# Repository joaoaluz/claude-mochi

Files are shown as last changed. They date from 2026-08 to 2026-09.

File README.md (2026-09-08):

# claude-mochi

Um mochi de mesa cujos **olhos indicam o consumo de tokens do Claude Code**.

Quanto mais da sua cota de **5 horas** você gasta, mais os olhos se fecham e
mais quente fica a cor da íris — verde → âmbar → vermelho. A barrinha embaixo
mostra o mesmo número, com precisão que a pálpebra só sugere. Passou de 95%
(ou rodou `/compact`), o mochi fica de olhos tontos (`X_X`). Sem notícias do
PC por 30 s, ele cochila.

Olhos e barra escolhem a métrica de forma independente, em `OLHOS_METRICA` e
`BARRA_METRICA` no `.ino`: qualquer um dos dois pode apontar para a janela de
contexto em vez do limite de 5 horas.

Inspirado no [clawd-mochi](https://github.com/yousifamanuel/clawd-mochi) do
Yousif Amanuel — mesma ideia de hardware, mas ligado ao Claude Code em vez de
funcionar offline por um hotspot.

> Projeto independente de fã, sem vínculo com a Anthropic.

---

**Vai construir?** Siga **[docs/PASSO-A-PASSO.md](docs/PASSO-A-PASSO.md)** — o
caminho completo em 8 fases, do saquinho de peças ao case impresso, com um teste
que fecha cada fase.

**Só a bancada?** **[docs/PROTOBOARD.md](docs/PROTOBOARD.md)** cobre a montagem na
protoboard em mais detalhe, sem case e sem solda no circuito. O firmware roda uma
animação de boot que valida display e fiação sem depender do PC.

**O que aparece na tela:** [`docs/tela/tela-mochi.svg`](docs/tela/tela-mochi.svg) —
todas as telas em escala 1:1 (rampa de contexto, piscar, cochilar, `X_X`) mais uma
proposta de expressões vindas dos hooks. O desenho é gerado por
`docs/tela/gera_svg.py`, que copia as constantes e a matemática inteira do
`.ino`; mexeu no firmware, rode o script de novo.

---

## Como funciona

A **status line** do Claude Code roda a cada mensagem do assistente e recebe um
JSON no stdin que já traz tudo pronto:

```json
"context_window": { "used_percentage": 72, "context_window_size": 200000 },
"rate_limits":    { "five_hour": { "used_percentage": 41 } },
"cost":           { "total_cost_usd": 1.2345 }
```

**Por que não usar a API ou um scraper da página de usage:** a Usage & Cost
Admin API exige uma *Admin API key* (`sk-ant-admin01-…`), que só existe para
organizações do Console — a documentação diz explicitamente que *"the Admin API
is unavailable for individual accounts"*. Além disso ela mede o consumo da API
de desenvolvedor, não o da assinatura Pro/Max, e os dados chegam com ~5 min de
atraso em buckets de 1m/1h/1d. A status line é instantânea, local, sem chave e
funciona em qualquer tipo de conta.

---

## Escolha a ligação: serial ou Wi-Fi

O firmware suporta as duas. Escolha no topo do `.ino` (`LINK_SERIAL` /
`LINK_WIFI`) e na variável `MOCHI_LINK` do lado do PC.

### Serial pelo USB — **padrão e recomendado**

```
Claude Code ──stdin──▶ statusline ──escreve arquivo──▶ ponte (mochi.py) ──USB──▶ ESP8266
                       (nunca toca                     (abre a porta UMA vez,
                        na porta serial)                reenvia a cada 5 s)
```

Funciona **em qualquer rede, ou sem rede nenhuma**. É o modo certo se:

- o PC está numa rede e o mochi em outra (o caso comum: Wi-Fi corporativo com
  WPA2-Enterprise, portal cativo ou registro de MAC, onde o ESP8266 não entra);
- a rede tem **isolamento de cliente** (*AP isolation*), que bloqueia tráfego
  entre dispositivos — a maioria das redes de empresa tem, e nesse caso o modo
  Wi-Fi não funcionaria **nem estando na mesma SSID**;
- o mDNS não atravessa a segmentação de VLAN da rede.

De brinde: sem credenciais no firmware, e como o rádio é desligado sobra RAM
para o display e o consumo cai ~20 mA. O mochi já vai estar no USB para ter
energia de qualquer forma.

**O detalhe que define a arquitetura:** no ESP8266 (NodeMCU / D1 mini), abrir a
porta serial aciona DTR/RTS e **reinicia a placa**. Se a status line abrisse a
porta a cada mensagem, o mochi reiniciaria dezenas de vezes por sessão. Por isso
existe o daemon: ele abre a porta uma única vez, e a status line só escreve um
arquivo de estado (escrita atômica: grava em `.tmp` e renomeia).

Um FIFO seria o instinto natural aqui, mas **escrever num FIFO sem leitor trava
para sempre** — penduraria o seu terminal se o daemon morresse. Arquivo comum
degrada em silêncio: fica velho e pronto.

O daemon reenvia o estado a cada 5 s mesmo sem mudança, então se o ESP reiniciar
ele se recupera sozinho.

### Wi-Fi (HTTP na rede local)

Só use se o PC e o mochi estiverem na **mesma rede sem isolamento de cliente** —
tipicamente a sua rede de casa. O ESP entra como cliente (não cria hotspot) e
responde em `http://mochi.local`.

| Rota | Efeito |
|---|---|
| `GET /` | página de status |
| `GET /state` | JSON com o estado atual |
| `GET /tokens?ctx=42&win=63&state=busy` | atualiza os olhos |
| `GET /backlight?on=0\|1` | apaga/acende a tela |

### E se o mochi ficar em casa e você no trabalho?

Aí não tem jeito de ser direto: seria preciso um intermediário na internet
(um broker MQTT público como o HiveMQ, ou um endpoint que o ESP fica
consultando). Dá para fazer, mas vale perguntar se compensa — se o mochi está
em casa, você não está olhando para ele. O caso que faz sentido é ele estar na
sua mesa, ao lado do notebook, e aí **serial resolve.**

---

## Lista de materiais

| Item | Obs |
|---|---|
| **ESP8266** (NodeMCU, Wemos D1 mini ou ESP-12) | 3,3 V — ideal para o display |
| **Display ST7789 240×240 SPI**, 1.54" ou 1.3" | veja a seção abaixo. **VCC só em 3,3 V, nunca 5 V** |
| Jumpers dupont fêmea-fêmea 10 cm | 7 fios (ou 6, se o módulo não tiver CS) |
| 2× parafuso M2×6 mm | prende o display |
| Fita dupla face fina | fixa a placa do ESP |
| Cabo USB | alimentação **e** dados (no modo serial os dois são usados) |
| Filamento PLA ou PETG | branco leitoso fica ótimo |

**Opcionais que valem a pena:** insertos roscados M2 (heat-set), botão tátil
6×6 mm para trocar de modo, buzzer piezo passivo (bipe no hook `Stop`), 1–3
LEDs WS2812B para as bochechas.

**Não é preciso nenhum resistor.** O ESP8266 e o display são ambos 3,3 V — não
há divisor de tensão, level shifter nem pull-up neste circuito.

### Qual display comprar

**Primeira escolha: ST7789 IPS 1.54" 240×240 SPI.** Área ativa de ~27,7 mm
contra ~23,4 mm da versão 1.3" — num rosto de mochi esses milímetros viram
olhos visivelmente maiores. É também o tamanho usado pelo projeto de referência.

**Alternativa igualmente boa: 1.3" 240×240 ST7789**, mais barata e bem mais
comum no Brasil. Mesmo controlador, mesma resolução, **firmware idêntico** — só
muda `scr_active` no `.scad`.

**7 ou 8 pinos, tanto faz.** Os módulos vêm em duas variantes:

| Variante | Pinos | CS |
|---|---|---|
| 8 pinos | GND VCC SCL SDA RES DC BLK **CS** | tem |
| 7 pinos | GND VCC SCL SDA RES DC BLK | não tem — fica em GND internamente |

A única desvantagem do sem-CS é não poder dividir o barramento SPI com outro
periférico, e aqui o display é o único dispositivo no SPI. Se o seu não tiver
CS, troque `#define TFT_CS D8` por `#define TFT_CS -1` no topo do `.ino` e não
ligue esse fio — sobra um GPIO.

**Checklist para aprovar um anúncio:**

| | |
|---|---|
| ✅ **Aprova** | controlador **ST7789** (ou ST7789V / ST7789VW), **240×240**, **1.54"** ou **1.3"**, **SPI**, **3,3 V** |
| ❌ **Rejeita** | ST7735 / ILI9341 / ILI9488 (outro controlador, outro código) · 240×280, 135×240, 320×240 (resolução diferente, quebra o layout dos olhos) · **GC9A01** (funciona, mas é redondo — é o caminho dos dois olhos separados, outro projeto) · só 5 V · com touch (não usamos e encarece) |
| ⚠️ **Confirmar** | quantos pinos (7 sem CS / 8 com CS) · barra de pinos soldada ou solta |

> **Duas armadilhas que não aparecem na lista de peças:**
>
> 1. O módulo quase sempre vem com a **barra de pinos solta, não soldada** — sem
>    soldar não encaixa em jumper nem protoboard. Precisa de ferro de solda.
> 2. O **cabo USB precisa ter fios de dados**. Muito cabo barato é só de carga e
>    nem enumera a porta serial — no modo serial isso é fatal, e o sintoma é
>    confuso (a placa liga e a tela acende, mas nenhuma porta aparece no PC).

**O Arduino Uno não entra neste projeto.** Sem Wi-Fi, lógica 5 V (mataria o
display de 3,3 V sem level shifter) e 2 KB de RAM — não anima 240×240. E se a
ideia fosse o próprio microcontrolador chamar a API da Anthropic, precisaria de
TLS: o Uno não tem, e o ESP8266 gastaria 16–30 KB de RAM dos 80 KB só no
handshake, brigando com o display — além de exigir a chave gravada no firmware.

---

## Ligações

Alimente o display **apenas com 3,3 V**.

| Display | ESP8266 | GPIO |
|---|---|---|
| VCC | 3V3 | — |
| GND | GND | — |
| SCL / SCK | D5 | GPIO14 |
| SDA / MOSI | D7 | GPIO13 |
| RES / RST | D2 | GPIO4 |
| DC | D1 | GPIO5 |
| CS | D8 | GPIO15 — *só se o módulo tiver esse pino* |
| BLK | **3V3** | ou D6/GPIO12, se quiser controlar o brilho (`USE_BLK_PIN 1`) |

`SCK` e `MOSI` são fixos (SPI por hardware); os outros são configuráveis no topo
do `.ino`. Evite D0/D3/D4 para o display — são pinos de boot no ESP8266.

Módulo de 7 pinos (sem CS): pule essa linha e use `#define TFT_CS -1`.

---

## Firmware

1. Arduino IDE 2.x → **Preferences → Additional Boards Manager URLs**:
   `https://arduino.esp8266.com/stable/package_esp8266com_index.json`
2. **Boards Manager** → instalar *esp8266 by ESP8266 Community*.
3. **Library Manager** → instalar *Adafruit GFX Library* e *Adafruit ST7735 and
   ST7789 Library*.
4. Abrir `firmware/claude_mochi/claude_mochi.ino`, conferir `LINK_SERIAL` /
   `LINK_WIFI` no topo, selecionar a placa e gravar.
5. **Só no modo Wi-Fi:** antes de gravar,
   `cp firmware/claude_mochi/config.example.h firmware/claude_mochi/config.h`
   e preencha SSID e senha (`config.h` está no `.gitignore`).

**Se a imagem sair com ruído:** baixe `setSPISpeed` de `40000000` para
`20000000`. **Se sair de cabeça para baixo ou espelhada:** ajuste
`tft.setRotation(0..3)`.

### Protocolo serial

Uma linha por atualização, pares `chave=valor` separados por espaço, terminada
em `\n`, a 115200 bps. Chaves: `ctx`, `win`, `state`. O firmware responde `ok`.

```
ctx=42 win=63 state=busy
```

Dá para testar à mão pelo Monitor Serial da Arduino IDE antes de montar o resto.

---

## Lado do PC

Dois caminhos para o mesmo resultado:

| | Quando usar | Precisa de |
|---|---|---|
| **`host/mochi.py`** | Windows, macOS, Linux. **Único que funciona no Windows.** | Python + `pyserial` |
| `host/*.sh` | Só se você já tem os scripts bash rodando no Linux/macOS | `bash`, `jq`, `curl` |

O `mochi.py` faz sozinho o que antes eram três arquivos: status line, hooks e
ponte serial. Ele não usa `bash` nem `jq` de propósito — no Windows nenhum dos
dois existe por padrão, e a status line do Claude Code lá é executada pelo Git
Bash (quando instalado) ou pelo PowerShell.

### Windows + Claude Desktop — plugou, funcionou

```bash
pip install pyserial
python host/mochi.py install
```

E reinicie o Claude Desktop. Só isso.

O `install`:

- copia o `mochi.py` para `~/.claude/`;
- faz backup do seu `settings.json` (`settings.json.bak-mochi`);
- escreve a `statusLine` e os hooks, **preservando** o que já estava lá;
- sobe a ponte serial.

Rodar de novo é seguro — ele troca a própria configuração em vez de duplicar.

A partir daí não há passo manual nenhum: **a status line sobe a ponte sozinha**
quando percebe que não tem nenhuma viva. Abrir o notebook, plugar o mochi e
abrir o Claude já basta. Sem systemd, sem Agendador de Tarefas.

Para conferir tudo de uma vez:

```bash
python host/mochi.py doctor
```

Ele mostra as portas com uma nota cada, qual foi escolhida, se a ponte está
viva, o que a status line publicou por último e se o `settings.json` está
apontando para o mochi.

### Achando a placa

`mochi.py ports` dá uma nota para cada porta em vez de chutar:

```
 nota  porta    descricao                              motivo
  100  COM5     USB-SERIAL CH340 (COM5)                adaptador conhecido: CH340
 -100  COM3     Standard Serial over Bluetooth link    ignorada (bluetooth)
```

Isso importa mais do que parece: num Windows típico a maioria das portas COM é
Bluetooth — a máquina onde isto foi testado tinha oito. A escolha combina
VID:PID conhecido (CH340, CH9102, CP2102, FT232, ESP32 nativo…), descrição, e
uma lista de exclusão para portas virtuais.

Quando sobra mais de uma candidata forte, a ponte **pergunta para cada uma**:
manda uma linha e vê quem responde `ok`. Duas placas ligadas juntas deixaram de
ser um impasse.

A ponte também redescobre a porta a cada reconexão e guarda a última que
funcionou em `~/.claude/mochi-port`. Trocar o cabo de entrada USB (COM5 → COM7)
se resolve sozinho, sem reiniciar nada.

Para forçar: `--port COM7` ou a variável `MOCHI_PORT`.

### Comandos

```bash
python host/mochi.py doctor            # diagnóstico completo
python host/mochi.py ports             # portas e a nota de cada uma
python host/mochi.py start | stop | restart
python host/mochi.py bridge -v         # ponte em primeiro plano, com log
python host/mochi.py send "ctx=50 win=80 state=busy"   # teste direto
python host/mochi.py uninstall         # tira do settings.json
```

Log da ponte de fundo: `~/.claude/mochi-bridge.log`.

### Uma ponte de cada vez

Só um processo pode segurar a porta serial. Se aparecer *"a porta está ocupada"*,
o culpado é quase sempre:

1. **outra ponte já rodando — inclusive dentro do WSL.** Uma ponte no WSL e outra
   no Windows disputando a mesma COM é o erro mais comum de quem migrou. Use
   `mochi.py stop`, ou encerre a do WSL.
2. o Monitor Serial da Arduino IDE aberto.

A ponte se recusa a subir se já houver outra viva, e a mensagem de erro diz
exatamente isso em vez de mostrar um `PermissionError` cru.

### Linux e macOS

O `mochi.py` funciona igual (`python3 host/mochi.py install`). Se preferir os
scripts bash antigos, eles continuam válidos:

```bash
cp host/statusline-mochi.sh host/mochi-mode.sh ~/.claude/
chmod +x ~/.claude/statusline-mochi.sh ~/.claude/mochi-mode.sh
```

e copie o bloco `statusLine`/`hooks` de `host/settings.example.json`.

No Linux, se der erro de permissão na porta: `sudo usermod -aG dialout $USER` e
reconecte a sessão.

Para deixar a ponte rodando como serviço em vez de contar com o autostart —
systemd de usuário:

```ini
# ~/.config/systemd/user/mochi.service
[Unit]
Description=claude-mochi serial bridge
[Service]
ExecStart=%h/.claude/mochi.py bridge
Restart=always
RestartSec=3
[Install]
WantedBy=default.target
```

```bash
systemctl --user daemon-reload && systemctl --user enable --now mochi
```

No macOS o equivalente é um `launchd` plist em `~/Library/LaunchAgents/`.

### Variáveis de ambiente

| Variável | Padrão | Para quê |
|---|---|---|
| `MOCHI_PORT` | autodetect | força a porta serial |
| `MOCHI_LINK` | `serial` | `serial`, `http` ou `both` |
| `MOCHI_HOST` | `mochi.local` | destino no modo http |
| `MOCHI_AUTOSTART` | `1` | `0` desliga o autostart da ponte |
| `MOCHI_STATE_FILE` / `MOCHI_MODE_FILE` | `~/.claude/mochi-*` | onde ficam os arquivos de estado |

### Modo Wi-Fi

```bash
export MOCHI_LINK=http
export MOCHI_HOST=mochi.local     # ou o IP, se o mDNS não funcionar na sua rede
```

Nesse modo não precisa da ponte: a status line fala direto com o ESP.

### Skill: instalar em outra máquina

O repositório traz uma skill em `.claude/skills/claude-mochi/`. Com o
repositório clonado, plugue o mochi e peça ao Claude *"instala o mochi aqui"* —
ela cobre instalação, diagnóstico e os erros comuns (porta ocupada, driver
CH340 faltando, cabo só de carga, status line que não aparece no Windows).

---

## Case 3D

Há **dois** modelos no repositório, ainda não consolidados:

| pasta | para qual placa | estado |
|---|---|---|
| `case/mochi.scad` | ESP8266 + display, **com** janela de tela | renderizado e fechado; medidas de componente ainda por conferir |
| `hardware/mochi.scad` | Raspberry Pi Zero / Pico, **sem** janela de tela | renderizado, sólido fechado, STLs em [`hardware/stl/`](hardware/stl) |
| `case/clawd_tela.scad` | **forma do Clawd**, só o display dentro | corta a janela nas malhas do `clawd_mochi.3mf`; as duas peças fecham (`Volumes: 2`) |

O `hardware/` nasceu de um pedido separado, feito sem saber que o `case/` já
existia — então é o modelo validado geometricamente, mas mira a placa errada
para este projeto. O caminho natural é levar para o `case/` o que foi provado
ali (perfil do corpo, pilares de canto embutidos na parede, `assert` de encaixe
da placa) e ficar com um modelo só. Até lá, **o case do projeto é o `case/`** — o
`hardware/` fica como referência, com guia próprio em
[`hardware/README.md`](hardware/README.md) e `make stl` na raiz.

### case/ — ESP8266 com display

`case/mochi.scad` é um modelo **paramétrico** em OpenSCAD. O corpo é o casco
convexo de 12 esferas em três andares (base larga, barriga, cúpula), o que dá a
forma redonda de mochi e permite calcular a parede interna exata só reduzindo o
raio das esferas — sem `minkowski()`, que é lentíssimo.

```bash
openscad -D 'part="front"' -o front.stl case/mochi.scad
openscad -D 'part="back"'  -o back.stl  case/mochi.scad
```

Use `part="preview"` para ver as duas metades montadas.

> ⚠️ **A geometria já foi renderizada; as medidas de componente não.**
> As duas metades exportam como um sólido fechado e conexo cada uma (CGAL:
> `Simple: yes`, uma peça por STL). O que continua sendo estimativa são as
> medidas do seu display e da sua placa: antes de imprimir, **meça com
> paquímetro** e preencha as variáveis no topo do arquivo — principalmente
> `scr_pcb_w/h`, `scr_active`, `scr_active_dy`, `brd_l/w` e `usb_w/h/z`.
> Os valores atuais são estimativas para um ST7789 1.54" e um Wemos D1 mini
> (NodeMCU v3 é bem maior: 58 × 31 mm). E ninguém imprimiu isto ainda.

**Impressão:** PLA ou PETG, camada 0,15–0,20 mm, 15% de preenchimento. Imprima a
casca frontal com o rosto virado para a mesa — a janela sai sem suporte (a
orientação `part="front"` já faz isso). Folga de 0,3 mm em volta do display e
0,3 mm no lábio da tampa.

### case/clawd_tela.scad — a forma do Clawd, com janela

Trabalha em cima das **malhas do seu `clawd_mochi.3mf`** (Bambu Studio),
extraídas para `models/upstream/3mf-corpo.stl` e `3mf-chapa.stl`. São as duas
peças do [clawd-mochi](https://github.com/yousifamanuel/clawd-mochi): chapa
frontal de 2 mm e corpo com cavidade **passante** de 48,50 × 32,25 mm — no seu
projeto o corpo está achatado em Z, de 38 para **28 mm** (`m22 = 0,7368` na
matriz do objeto). Esse achatamento está reproduzido em `escala_z`.

O modelo original tem a cara vazada (boca de 9 × 3,25 mm e dois furinhos de
3,5 mm nas orelhas), não uma tela. O `.scad` acrescenta:

1. **janela** da área ativa, 28,5 × 28,5 mm, com chanfro de 45° na face de fora
2. **tampa da boca**, que ficaria mordida pela borda da janela
3. **moldura interna** que segura a PCB contra a chapa, com saia a 45° para
   imprimir sem suporte nessa região

As malhas de origem **não são versionadas** (`.gitignore` barra `*.stl` e
`*.3mf`, e são geometria de terceiro sob CC BY-NC-SA). Regenere a partir do seu
projeto do fatiador e exporte as peças:

```bash
python3 models/extrai_3mf.py clawd_mochi.3mf
```

```bash
make clawd
```

Ou peça por peça, sem `make`:

```bash
openscad -o case/stl/clawd-chapa.stl -D 'part="chapa"' case/clawd_tela.scad
```

Sem parafuso nenhum: a chapa **cola** no aro do corpo. Só o display vai dentro;
o ESP8266 fica fora e os fios saem pelo fundo, que já é aberto.

A placa do display (31,5 mm) contra a cavidade (32,25 mm) deixa **0,375 mm por
lado**. Aperta. Existe `alargar` para comer parte da parede de trás, mas ele só
corta os `alargar_z` mm de cima: a faixa maciça em Y −10,75..−12,5 fecha o fundo
da cavidade e é de onde saem as quatro perninhas — cortá-la inteira solta as
perninhas do corpo.

> ⚠️ As medidas do display são **estimativa** (`pcb_x`, `pcb_y`, `ativa`,
> `ativa_dx`). Meça o seu módulo com paquímetro antes de imprimir.

**Voltando para o fatiador:** `make clawd-3mf` gera `clawd_mochi_tela.3mf`, o seu
projeto com as duas malhas trocadas — todos os ajustes de fatiamento, perfis e a disposição no prato
foram preservados; só a escala em Z saiu da matriz e foi assada na malha. As
miniaturas guardadas ainda mostram o modelo antigo, sem janela; elas se
regeneram quando você fatiar.

**Licença:** os modelos de origem são CC BY-NC-SA 4.0 — não comercial, com
atribuição. O que sai daqui é derivado e herda a mesma licença.

### Alternativa

Os modelos do projeto original (`models/clawd_mochi/clawd_mochi_v1.stl` e
`.3mf`) estão sob **CC BY-NC-SA 4.0** — uso não comercial, com atribuição e
compartilhamento pela mesma licença. Só que foram desenhados em volta de um
ESP32-C3 Super Mini (22,5 × 18 mm); um NodeMCU não cabe. Se o seu ESP8266 for um
Wemos D1 mini, vale testar; se for NodeMCU, o `.scad` daqui é o caminho.

---

## Próximos passos possíveis

- Dois displays redondos GC9A01 1.28" — um olho físico por tela, com contexto num
  e limite de 5h no outro (compartilham SPI, cada um com seu CS).
- Buzzer no hook `Stop` para avisar que a tarefa terminou.
- LEDs de bochecha acompanhando a cor da íris.
- Bateria LiPo + TP4056 com proteção (o backlight puxa 30–60 mA, então a
  autonomia real é de poucas horas).

## Licença

Código sob MIT. Se você reaproveitar os STLs do `clawd-mochi`, eles seguem sob
CC BY-NC-SA 4.0 do autor original.

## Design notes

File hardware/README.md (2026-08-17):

# Modelo para impressão 3D — carcaça do claude-mochi

Carcaça paramétrica do assistente de mesa, feita em OpenSCAD. São **duas peças**,
as duas impressas **sem suporte nenhum**:

| peça | arquivo | o que tem |
|---|---|---|
| `casca` | `stl/<placa>-casca.stl`  | corpo do mochi, oco, rostinho gravado, grelha frontal, aberturas das portas e os 4 pilares de parafuso |
| `base`  | `stl/<placa>-base.stl` | tampa do fundo, espaçadores da PCB, rasgos de ventilação, escareados e rebaixos para pés de borracha |

<p align="center">
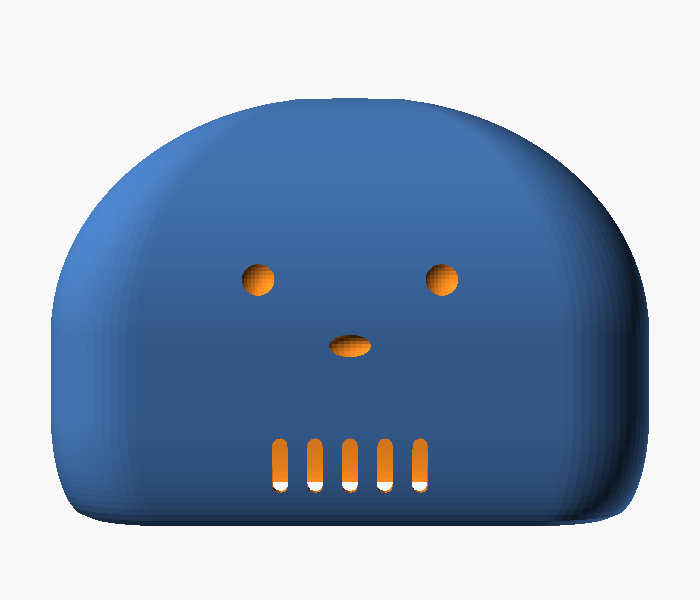
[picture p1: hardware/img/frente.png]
Vista frontal da casca
  
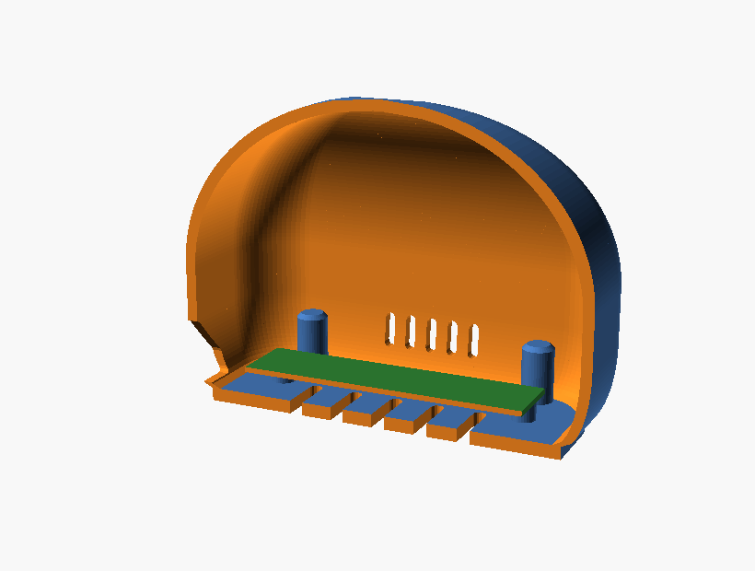
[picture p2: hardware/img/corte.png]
Corte mostrando o interior
  
</p>
<p align="center">
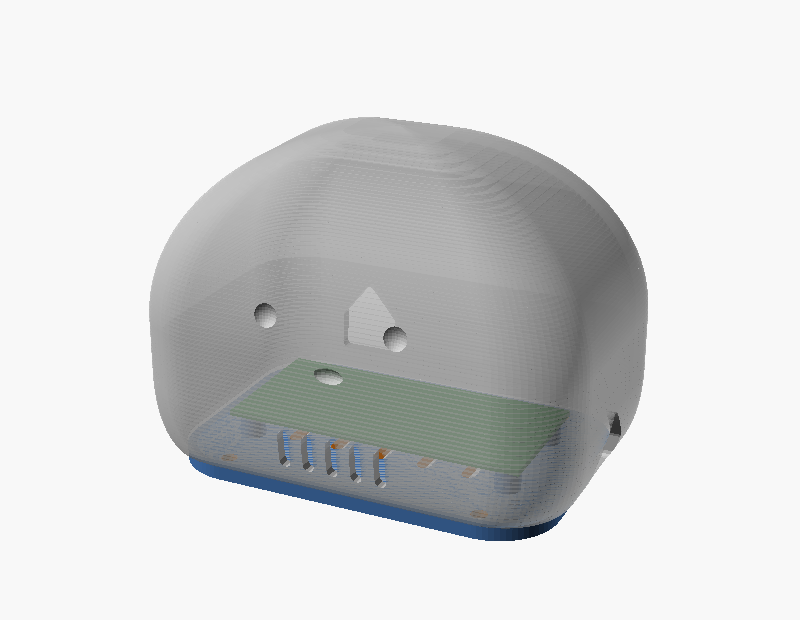
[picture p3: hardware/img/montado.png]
Conjunto montado
  
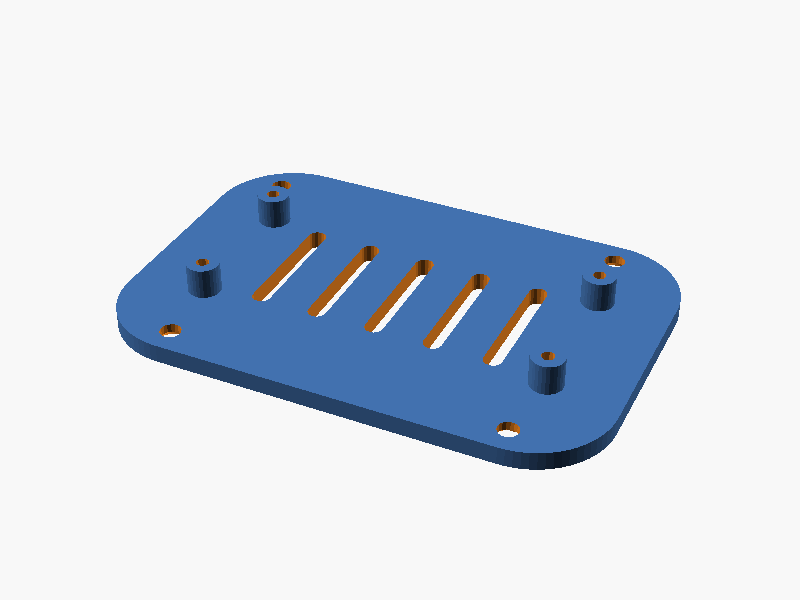
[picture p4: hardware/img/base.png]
Base com os espaçadores
  
</p>

## Medidas

| placa | corpo (L × P × A) | altura total com a base | material (par completo) |
|---|---|---|---|
| `pi_zero` (Pi Zero / Zero 2 W) | 94 × 64 × 68 mm | 71 mm | ≈ 60 g de PLA |
| `pico` (Raspberry Pi Pico) | 76 × 52 × 56 mm | 59 mm | ≈ 40 g de PLA |

Cabe em qualquer mesa de impressão a partir de 100 × 100 mm.

## Lista de material

- 4 × parafuso **M3 × 12** auto‑atarraxante, cabeça escareada — prende a base na casca
- 4 × parafuso **M2,5 × 6** (Pi Zero) ou **M2 × 6** (Pico) — prende a PCB nos espaçadores
- 4 × pé adesivo de borracha Ø 9 mm (opcional, há rebaixo para eles)

Prefere insertos térmicos M3 nos pilares? Gere a casca com
`-D screw_pilot=4.0` e instale os insertos com o ferro de solda.

## Gerando os arquivos

Os STL já estão em [`stl/`](stl), prontos para fatiar. Para regerar:

```bash
sudo apt install openscad     # ou: brew install --cask openscad
make stl                      # exporta as 4 peças em hardware/stl/
```

Peça por peça, direto no OpenSCAD:

```bash
openscad -o casca.stl -D 'part="casca"' -D 'board_name="pi_zero"' hardware/mochi.scad
openscad -o base.stl  -D 'part="base"'  -D 'board_name="pi_zero"' hardware/mochi.scad
```

Para olhar antes de imprimir, abra `hardware/mochi.scad` no OpenSCAD e use o
Customizer (todos os parâmetros estão agrupados). O parâmetro `part` aceita:

- `"casca"` / `"base"` — cada peça sozinha
- `"chapa"` — as duas lado a lado, já na orientação de impressão
- `"montado"` — conjunto montado, com a placa desenhada por dentro
- `"corte"` — meia‑seção, para conferir folgas e altura das aberturas

## Perfil de fatiamento

| item | valor |
|---|---|
| orientação | **exatamente como está no STL** — casca com a boca para baixo, base com os espaçadores para cima |
| suportes | **nenhum** (as aberturas têm teto em 45°, os rasgos são autoportantes) |
| altura de camada | 0,2 mm |
| perímetros | 3 |
| preenchimento | 15 % (giroide) |
| topo / fundo | 4 camadas |
| material | PLA; PETG se o mochi for ficar em sol ou perto de fonte de calor |

Dicas que fazem diferença:

- **Topo da cúpula**: é a única região com ângulo raso. Ative *ironing*, ou reduza
  a camada para 0,12 mm nos últimos 8 mm, se quiser acabamento liso.
- **Primeira camada da casca**: o contato com a mesa é só um anel de ~2 mm.
  Use *brim* de 5 mm se sua mesa não for muito aderente.
- **Furos‑guia**: os pilares e espaçadores já vêm com o furo certo para parafuso
  auto‑atarraxante. Não escareie — a rosca se forma no plástico.

## Montagem

1. Limpe as rebarbas das aberturas e dos furos‑guia.
2. Parafuse a PCB nos quatro espaçadores da base (M2,5 × 6 no Pi Zero) — aperte
   só até encostar.
3. Encaixe a casca sobre a base alinhando os cantos; a base entra por baixo com
   0,5 mm de recuo, formando um rasgo de sombra.
4. Prenda com os quatro M3 × 12 por baixo, em cruz.
5. Cole os pés de borracha nos rebaixos.
6. Ligue o cabo por fora, pela abertura traseira. No Pi Zero o cartão microSD
   sai pela abertura da lateral direita, sem precisar abrir a caixa.

## Ajustando o modelo

Principais parâmetros de `mochi.scad`:

| parâmetro | padrão | efeito |
|---|---|---|
| `board_name` | `"pi_zero"` | `"pi_zero"` ou `"pico"`; define tamanho, furos e portas |
| `board_rot` | padrão da placa | gira a placa dentro da caixa (0/90/180/270) — muda por qual parede o cabo sai |
| `open_ports` | padrão da placa | quais aberturas abrir, por nome |
| `body_w` / `body_d` / `body_h` | 0 (= padrão da placa) | força as medidas externas |
| `s_bottom` | 0,88 | quanto o corpo estreita na base (menor = mais gotinha) |
| `t_fillet` / `t_dome` | 0,24 / 0,42 | onde termina o arredondado de baixo e onde começa a cúpula |
| `corner_f` | 0,24 | raio dos cantos em planta |
| `wall` | 2,4 mm | espessura da parede |
| `face` / `face_depth` | `true` / 1,0 mm | rostinho gravado |
| `vents` / `feet` | `true` | grelha + rasgos de ar / rebaixo dos pés |
| `layers_n` | 72 | fatias usadas para gerar a curva (menos = render mais rápido) |

Exemplo — mochi liso, sem rosto, com as duas portas USB e o microSD abertos:

```bash
openscad -o casca.stl -D 'part="casca"' -D 'face=false' \
  -D 'open_ports=["usb-pwr","usb-data","microsd"]' hardware/mochi.scad
```

Os pilares de parafuso não têm posição fixa: cada um corre pelo arco do seu
canto e para no ponto mais distante da placa **e** de todas as aberturas que
você abriu. Por isso dá para girar a placa ou abrir outra porta sem colisão.

## Colocando outra placa

Edite `boards.scad` e acrescente uma linha em cada função, usando o mesmo nome:
tamanho, furos, furo‑guia, raio do espaçador, portas, portas abertas por padrão,
rotação padrão e tamanho sugerido do corpo. As coordenadas são as do PCB visto
de cima, com origem no canto inferior‑esquerdo.

O modelo se recusa a gerar peça errada: se a placa não couber na abertura do
fundo, se um pilar bater na PCB ou se a parede ficar fina demais para o rosto,
o OpenSCAD para com uma mensagem dizendo qual parâmetro mexer.

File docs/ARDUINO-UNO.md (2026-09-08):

# Arduino Uno — dá para usar?

**Resumo: dá, mas é um downgrade em todos os eixos contra um ESP8266.** Este
documento existe porque a pergunta aparece sempre. Se você tem um NodeMCU ou
Wemos D1 mini na gaveta, use ele e ignore esta página.

Os números abaixo são de uma compilação real (`arduino:avr:uno`, core 1.8.6,
Adafruit GFX 1.11.9 + ST7789 1.10.3), não estimativa.

## O que não é problema

```
Sketch uses 17332 bytes (53%) of program storage space. Maximum is 32256 bytes.
Global variables use 623 bytes (30%) of dynamic memory, leaving 1425 bytes.
```

Cabe com folga. O medo comum — "240×240 não cabe em 2 KB de RAM" — não se
aplica: um framebuffer seriam 115 KB, mas o `Adafruit_ST7789` desenha direto no
display e nunca aloca isso. `sqrtf`, `strtok` e `millis()` existem no AVR.

O reset por DTR ao abrir a porta serial também acontece no Uno, então a razão de
existir do `host/mochi-serial.py` (abrir a porta uma vez só) continua valendo
igual.

## O que é problema

**1. Lógica de 5 V — o bloqueio de verdade.** O Uno chuta 5 V nos pinos e o
ST7789 é 3,3 V. Ligar direto degrada e eventualmente mata o display. São **5
linhas** a converter: SCK, MOSI, DC, CS e RST. (MISO não é usado — o firmware
nunca lê do display.)

**2. O rail de 3V3 do Uno R3 entrega só ~50 mA.** O ST7789 com backlight puxa
20–40 mA. Funciona, mas fica no limite, e é justamente o backlight ligado no
3V3 — como o guia da protoboard recomenda — que consome.

**3. Velocidade.** O AVR trava o SPI em `F_CPU/2` = 8 MHz contra os 40 MHz do
ESP8266, e roda a 16 MHz contra 80. Cada frame redesenha ~37 KB de pixels (as
duas caixas dos olhos), o que dá algo em torno de 45–60 ms por frame:
**~16–20 fps em vez dos 60** que o `delay(16)` do loop mira. A animação roda,
só que perceptivelmente mais dura. A animação de boot passa de ~1 s para ~3 s.

**4. Sem modo Wi-Fi.** O bloco `LINK_WIFI` deixa de existir. No modo serial,
que é o padrão, isso não muda nada.

## Convertendo 5 V → 3,3 V

Três saídas, da melhor para a mais improvisada.

### Opção A — módulo conversor de nível (recomendado)

Um módulo bidirecional de 8 canais com **TXS0108E**, ou de 4 canais com
**TXB0104**. É a solução limpa: alimenta com 5 V de um lado, 3,3 V do outro, e
passa as 5 linhas sem pensar. Barato e fácil de achar.

> ⚠️ Evite os módulos de 4 canais baseados em **MOSFET + resistor de pull-up**
> (os verdinhos de I²C). Eles são feitos para barramento aberto-dreno em
> centenas de kHz e não seguram SPI a 8 MHz.

### Opção B — CI buffer 74HC4050 / CD4050B

Um hex buffer (6 canais, cobre as 5 linhas com uma sobrando) **alimentado com
3,3 V**. As entradas dele toleram sinal acima do VDD, que é exatamente o truque
que queremos. Unidirecional 5 V → 3,3 V, que é tudo de que precisamos aqui.

### Opção C — divisores resistivos (sem comprar nada)

Se você já tem resistores, funciona. Um divisor por linha:

```
  pino do Uno (5 V) ──┬── R1 (1 kΩ) ──┬── pino do display (3,3 V)
                      │               │
                                      R2 (2 kΩ)
                                      │
                                     GND
```

`5 V × 2k/(1k+2k) = 3,33 V`. Não tem 2 kΩ? Dois de 1 kΩ em série resolvem.
1,8 kΩ + 3,3 kΩ também serve (`3,23 V`).

São **cinco** divisores, ou seja 10 resistores — é o que torna esta opção
chata na protoboard. A impedância de saída fica em ~667 Ω, o que a 8 MHz ainda
é tranquilo com jumpers curtos; se a imagem sair com ruído, encurte os fios ou
baixe o SPI para 4 MHz.

## Ligação

| Display ST7789 | Uno | Passa por conversor? |
|---|---|---|
| SCK / CLK | 13 | **sim** |
| SDA / MOSI | 11 | **sim** |
| DC | 9 | **sim** |
| CS | 10 | **sim** |
| RST | 8 | **sim** |
| BLK | 3V3 (ou pino 6) | não |
| VCC | 3V3 | não |
| GND | GND | não |

Se o 3V3 do Uno não der conta do display, alimente-o por um regulador
AMS1117-3.3 a partir do 5 V — **e junte os GNDs**.

## Ajustes no firmware

O `.ino` mira ESP8266: os labels `D8`/`D1`/`D2` não existem no AVR,
`analogWrite` é de 8 bits em vez de 10, e o `WiFi.forceSleepBegin()` não existe.
Troque o bloco de pinagem por:

```cpp
#define TFT_CS   10
#define TFT_DC   9
#define TFT_RST  8
#define TFT_BLK  6
#define BLK_MAX  255          // no ESP8266 seria 1023
```

E no `setup()`, apague as três linhas de desligar o rádio
(`WiFi.mode(WIFI_OFF)` e as duas seguintes) e baixe o SPI:

```cpp
tft.setSPISpeed(8000000);     // teto do AVR: F_CPU/2
```

Onde houver `analogWrite(TFT_BLK, 1023)`, use `BLK_MAX` — `1023` num AVR estoura
os 8 bits e o backlight se comporta de forma errada.

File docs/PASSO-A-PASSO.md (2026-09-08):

# Passo a passo — do zero ao mochi funcionando

Guia de construção para seguir de cima para baixo, numa sessão só. Cada fase
termina com um **teste**: se ele passar, a fase está pronta e você nunca mais
precisa voltar nela. Se falhar, o problema está no que você acabou de fazer —
não no resto.

**Ordem proposital:** hardware antes de software, e software antes do case. O
case é a última coisa: só vale imprimir depois de ter certeza de qual placa e
qual display cabem lá dentro.

| Fase | O que acontece | Tempo |
|---|---|---|
| [0](#fase-0--antes-de-encostar-no-ferro) | Conferir peças e instalar o que precisa de internet | 30 min |
| [1](#fase-1--soldar-a-barra-de-pinos-do-display) | Soldar a barra de pinos do display | 15 min |
| [2](#fase-2--ligar-os-fios) | Ligar os 7 (ou 8) fios | 15 min |
| [3](#fase-3--gravar-o-firmware) | Gravar o firmware e ver a animação de boot | 30 min |
| [4](#fase-4--testar-o-protocolo-na-mão) | Falar com o mochi pelo Monitor Serial | 10 min |
| [5](#fase-5--ligar-no-claude-code) | Status line + ponte serial | 20 min |
| [6](#fase-6--hooks-opcional) | Hooks (`busy` / `compact`) | 5 min |
| [7](#fase-7--deixar-rodando-sozinho) | Serviço que sobe junto com o sistema | 10 min |
| [8](#fase-8--o-case-3d) | Medir, ajustar o `.scad`, imprimir, montar | horas |

> Faltou alguma peça? Dá para fazer as fases 0 e 3–5 **sem o display**: o
> firmware grava e roda igual, e o Monitor Serial já responde `ok`. Você só não
> vê o rosto.

---

## Fase 0 — antes de encostar no ferro

### 0.1 Confira as peças

- [ ] ESP8266 (NodeMCU v2/v3 ou Wemos D1 mini)
- [ ] Display **ST7789 240×240 SPI**, 1.54" ou 1.3"
- [ ] Jumpers **fêmea-fêmea** (7 ou 8) — ou macho-fêmea + protoboard
- [ ] Cabo USB **com fios de dados**
- [ ] Ferro de solda + estanho (para a barra de pinos do display)

Duas conferências que evitam perder o dia:

**O display é mesmo ST7789 240×240?** Olhe o verso do módulo. Se estiver escrito
ST7735, ILI9341 ou GC9A01, é outro controlador e este firmware não serve. Se a
resolução for 240×280 ou 135×240, o layout dos olhos quebra.

**O cabo USB tem dados?** Plugue a placa no PC sem nada mais e rode:

```bash
ls /dev/ttyUSB* /dev/ttyACM* 2>/dev/null
```

Se não aparecer nada, ou o cabo é só de carga, ou falta o driver do conversor
(CH340 / CP2102). Resolva isso **agora** — no modo serial, sem porta não há
projeto. No Windows, o equivalente é procurar a porta COM no Gerenciador de
Dispositivos.

### 0.2 Instale o que depende de internet

Arduino IDE 2.x:

1. **Preferences → Additional Boards Manager URLs**, cole:
   `https://arduino.esp8266.com/stable/package_esp8266com_index.json`
2. **Boards Manager** → instale *esp8266 by ESP8266 Community*
3. **Library Manager** → instale *Adafruit GFX Library* e
   *Adafruit ST7735 and ST7789 Library* (aceite as dependências que ela pedir)

No PC:

```bash
pip install pyserial
```

`jq` também é obrigatório (a status line usa). No Linux: `sudo apt install jq`.
No macOS: `brew install jq`.

### 0.3 Linux: permissão da porta serial

```bash
sudo usermod -aG dialout $USER
```

**Faça agora**, porque só vale depois de sair e entrar de novo na sessão (ou
reiniciar). Descobrir isso na fase 5, com tudo montado, é frustrante à toa.

✅ **Teste da fase 0:** a placa aparece como porta serial no PC e a Arduino IDE
lista a placa "NodeMCU 1.0" (ou "LOLIN(WEMOS) D1 R2 & mini") no menu de placas.

---

## Fase 1 — soldar a barra de pinos do display

O módulo quase sempre vem com a barra de pinos **solta, dentro do saquinho**.
Sem soldar, nenhum jumper encaixa.

Truque para ficar reto: espete a barra numa protoboard, apoie a placa do display
por cima, e solde primeiro **um pino só** nas pontas. Confira o esquadro, corrija
reaquecendo esse pino, e só então solde o resto.

Solda rápida em cada pino — 2 a 3 segundos. O display é sensível ao calor.

✅ **Teste da fase 1:** todos os pinos brilhantes e cônicos (não em bola fosca),
nenhuma ponte de estanho entre pinos vizinhos. Olhe contra a luz.

---

## Fase 2 — ligar os fios

**Nada de resistor.** ESP8266 e display são ambos 3,3 V — sem divisor, sem level
shifter, sem pull-up.

> ⚠️ **Confira a linha VCC duas vezes antes de energizar. 5 V queima o display.**
> `VIN` e `5V` do ESP são 5 V. Você quer o pino escrito **3V3**.

| Display | ESP8266 | GPIO | Observação |
|---|---|---|---|
| GND | GND | — | |
| VCC | **3V3** | — | nunca 5 V / VIN |
| SCL / SCK | D5 | GPIO14 | fixo, SPI por hardware |
| SDA / MOSI | D7 | GPIO13 | fixo, SPI por hardware |
| RES / RST | D2 | GPIO4 | |
| DC | D1 | GPIO5 | |
| BLK | **3V3** | — | backlight sempre aceso, o mais simples |
| CS | D8 | GPIO15 | **só se o seu módulo tiver esse pino** |

**Seu módulo tem 7 pinos (sem CS)?** Não ligue fio nenhum aí e, na fase 3, troque
no topo do `.ino`:

```c
#define TFT_CS   -1
```

Isso é a causa nº 1 de "backlight aceso, tela branca, imagem nunca aparece".

Jumpers **curtos**. Fio longo em SPI a 40 MHz vira ruído na tela.

### Energizar sem gravar nada

Plugue o USB. Esperado: LED da placa aceso e **backlight do display aceso** —
tela branca ou cinza uniforme, sem imagem. Isso é o certo: ainda não há firmware.

Se nada acender, ou se qualquer coisa esquentar, tire da tomada e refaça
VCC/GND antes de seguir.

✅ **Teste da fase 2:** tela branca acesa, nada quente.

---

## Fase 3 — gravar o firmware

Abra `firmware/claude_mochi/claude_mochi.ino`.

Confira no topo do arquivo:

```c
#define LINK_SERIAL 1     // deixe assim — é o modo recomendado
#define LINK_WIFI   0
```

E, se o seu módulo não tem CS, o `#define TFT_CS -1` da fase 2.

> **Só se você escolheu Wi-Fi** (`LINK_WIFI 1`): antes de gravar,
> `cp firmware/claude_mochi/config.example.h firmware/claude_mochi/config.h`
> e preencha SSID e senha. O `config.h` está no `.gitignore`, então a senha não
> vai para o repositório. **Nesse modo o PC e o mochi precisam estar na mesma
> rede, sem isolamento de cliente** — se for rede de empresa, quase certamente
> não vai funcionar; fique no serial.

Selecione a placa e a porta, e grave.

**Esperado ao terminar a gravação:** os olhos varrem de arregalados a
semicerrados e voltam, com a cor indo de verde → âmbar → vermelho e a barra de
baixo enchendo — uns 3 segundos. Depois os olhos "cochilam" (viram um traço
fino), esperando notícias do PC.

Essa é a animação de boot (`BOOT_DEMO 1`). Ela não depende de rede, de status
line nem de ponte serial: é o teste de fiação puro.

### Se a imagem saiu, mas errada

| Sintoma | Correção |
|---|---|
| Listras, ruído, pixels aleatórios | baixe `setSPISpeed` de `40000000` para `20000000` |
| De cabeça para baixo ou espelhada | ajuste `tft.setRotation(0..3)` |
| Cores em negativo | acrescente `tft.invertDisplay(false);` depois do `tft.init(...)` |

✅ **Teste da fase 3:** a animação de boot rodou. **Seu hardware está pronto** —
daqui para frente é tudo software.

---

## Fase 4 — testar o protocolo na mão

Ainda sem tocar em nenhuma configuração do Claude Code.

Abra o **Monitor Serial** da Arduino IDE e ajuste **duas** coisas:

- velocidade: **115200**
- terminação de linha: **Nova linha (NL)**

> ⚠️ **É aqui que quase todo mundo trava.** O firmware só processa a linha
> quando recebe o `\n`. Com o Monitor Serial em "Sem final de linha" você digita,
> aperta enter e **não acontece absolutamente nada** — sem erro, sem pista.

Abrir o Monitor Serial reinicia a placa (DTR/RTS no ESP8266), então a animação
de boot roda de novo. Normal.

Digite e envie, uma linha de cada vez:

```
ctx=20 win=10 state=idle
```

Olhos bem abertos, verdes; a placa responde `ok`. Agora os extremos:

```
ctx=75 win=50 state=busy      -> semicerrados, âmbar, piscando rápido
ctx=97 win=90 state=idle      -> olhos de tonto (X_X)
ctx=0  win=0  state=idle      -> volta ao normal
```

Por fim, **pare de enviar por 30 segundos**: ele cochila sozinho. Isso confirma
o timeout de "sem notícias do PC".

✅ **Teste da fase 4:** os quatro comandos acima produzem quatro rostos
diferentes, e o mochi cochila sozinho depois de 30 s.

---

## Fase 5 — ligar no Claude Code

> **Feche o Monitor Serial antes de continuar.** Ele segura a porta, e a ponte
> não vai conseguir abrir.

### 5.1 Instale os scripts do lado do PC

> **No Windows (ou com o Claude Desktop), pule esta parte.** Estes scripts
> precisam de `bash` e `jq`, que o Windows nao tem. La use um comando so:
> `python host/mochi.py install`. Detalhes na secao "Lado do PC" do README.

```bash
cp host/statusline-mochi.sh ~/.claude/statusline-mochi.sh
cp host/mochi-mode.sh       ~/.claude/mochi-mode.sh
cp host/mochi-serial.py     ~/.claude/mochi-serial.py
chmod +x ~/.claude/statusline-mochi.sh ~/.claude/mochi-mode.sh ~/.claude/mochi-serial.py
```

### 5.2 Configure a status line

Abra `~/.claude/settings.json` e acrescente o bloco `statusLine` de
`host/settings.example.json`:

```json
"statusLine": {
  "type": "command",
  "command": "~/.claude/statusline-mochi.sh",
  "padding": 1
}
```

Se você já tem uma status line, só troque o `command`.

**Por que isso funciona:** a status line roda a cada mensagem do assistente e
recebe no stdin um JSON que já traz `context_window.used_percentage` e
`rate_limits.five_hour.used_percentage` prontos. O script imprime a status line
normal no terminal **e** grava esses números em `~/.claude/mochi-state`, com
escrita atômica (grava `.tmp`, renomeia). Ela nunca abre a porta serial —
se abrisse, o ESP reiniciaria a cada mensagem.

### 5.3 Suba a ponte serial

Numa aba separada do terminal:

```bash
~/.claude/mochi-serial.py -v
```

Ela detecta a porta sozinha (CH340 / CH9102 / CP2102 / FT232). Se tiver mais de
um conversor plugado, aponte na mão:

```bash
~/.claude/mochi-serial.py --port /dev/ttyUSB0 -v
```

No Windows, `--port COM3`.

O `-v` mostra cada linha enviada — vale muito na primeira vez. A ponte reenvia o
estado a cada 5 s mesmo sem mudança, então se o ESP reiniciar ele se recupera
sozinho.

### 5.4 Abra o Claude Code

Em outra aba, abra o Claude Code e mande qualquer mensagem. A cada resposta do
assistente os olhos devem reagir — e ir fechando conforme a conversa cresce.

✅ **Teste da fase 5:** o `-v` da ponte imprime linhas `ctx=… win=…` conforme
você conversa, e o rosto muda junto.

---

## Fase 6 — hooks (opcional)

A status line sozinha não sabe distinguir "o Claude está trabalhando" de "o
Claude está esperando você", nem detectar uma compactação. Os hooks resolvem
isso: o mochi pisca mais rápido enquanto trabalha e fica de olhos tontos durante
o `/compact`.

Copie o bloco `hooks` de `host/settings.example.json` para o seu
`~/.claude/settings.json` — são cinco eventos (`UserPromptSubmit`, `Stop`,
`PreCompact`, `PostCompact`, `SessionEnd`) chamando `~/.claude/mochi-mode.sh`.

Esses scripts escrevem num arquivo separado (`~/.claude/mochi-mode`) para não
brigar com o que a status line escreve; a ponte junta os dois numa linha só.
Nunca bloqueiam e nunca tocam na porta serial.

✅ **Teste da fase 6:** mande uma tarefa longa. Durante o trabalho, piscada
rápida; ao terminar, volta ao normal.

---

## Fase 7 — deixar rodando sozinho

Enquanto a ponte não estiver rodando, o mochi cochila. Para não ter que subir na
mão toda vez:

**Linux (systemd de usuário):**

```ini
# ~/.config/systemd/user/mochi.service
[Unit]
Description=claude-mochi serial bridge
[Service]
ExecStart=%h/.claude/mochi-serial.py
Restart=always
RestartSec=3
[Install]
WantedBy=default.target
```

```bash
systemctl --user daemon-reload && systemctl --user enable --now mochi
```

Conferir depois: `systemctl --user status mochi`.

**macOS:** o equivalente é um `launchd` plist em `~/Library/LaunchAgents/`.

**Só testando:** `nohup ~/.claude/mochi-serial.py &` resolve.

> Quando quiser regravar o firmware, **pare a ponte antes**
> (`systemctl --user stop mochi`) — senão ela segura a porta e a Arduino IDE não
> grava.

✅ **Teste da fase 7:** reinicie o PC, abra o Claude Code, e o mochi reage sem
você ter feito nada.

---

## Fase 8 — o case 3D

Deixe para depois de tudo funcionar na bancada.

> ⚠️ **A geometria do `case/mochi.scad` já foi renderizada; as medidas de
> componente não.** Elas são estimativas para um ST7789 1.54" e um Wemos D1
> mini. E ninguém imprimiu isto ainda — você vai ser o primeiro.

### 8.1 Meça com paquímetro e preencha

Abra `case/mochi.scad` e corrija, no topo, as variáveis que descrevem **as suas**
peças:

| Variável | O que medir |
|---|---|
| `scr_pcb_w`, `scr_pcb_h`, `scr_pcb_t` | placa do display: largura, altura, espessura |
| `scr_active` | lado da área ativa (27,7 mm no 1.54"; 23,4 mm no 1.3") |
| `scr_active_dy` | quanto a área ativa está deslocada do centro da placa |
| `brd_l`, `brd_w`, `brd_t` | a placa do ESP (D1 mini 34,2×25,6 · NodeMCU v3 58×31) |
| `usb_w`, `usb_h`, `usb_z` | o conector USB e a altura do centro dele |

O `body_w/d/h` só precisa mexer se a sua placa não couber — o arquivo tem
`assert` de encaixe e vai reclamar em vez de gerar um case impossível.

### 8.2 Veja montado antes de exportar

Abra no OpenSCAD com `part="preview"` para ver as duas metades juntas. Depois:

```bash
openscad -D 'part="front"' -o front.stl case/mochi.scad
openscad -D 'part="back"'  -o back.stl  case/mochi.scad
```

### 8.3 Imprimir

PLA ou PETG, camada 0,15–0,20 mm, 15% de preenchimento. Imprima a casca frontal
com o rosto virado para a mesa — a janela sai sem suporte, e a orientação de
`part="front"` já faz isso. As folgas (0,3 mm em volta do display, 0,3 mm no
lábio da tampa) já estão no modelo.

Branco leitoso fica ótimo: o backlight atravessa um pouco a parede e o rosto
inteiro ganha um brilho suave.

### 8.4 Montar

2 parafusos M2×6 mm prendem o display; fita dupla face fina segura a placa do
ESP. Passe o cabo pelo recorte do USB antes de fechar as metades.

> O `hardware/mochi.scad` é **outro** modelo — mira Raspberry Pi Zero / Pico e
> não tem janela de tela. Ele existe como referência geométrica validada
> (`make stl` na raiz gera os STLs dele). Para este projeto, o case é o `case/`.

---

## Quando algo dá errado

| Sintoma | Causa provável |
|---|---|
| Backlight aceso, tela branca, nunca aparece imagem | `RES` ou `DC` no pino errado; ou `#define TFT_CS D8` num módulo sem CS |
| Tela totalmente apagada | `BLK` sem 3,3 V, ou `VCC` sem contato |
| Listras, ruído ou pixels aleatórios | jumper longo demais; baixe `setSPISpeed` para `20000000` |
| Imagem de cabeça para baixo ou espelhada | ajuste `tft.setRotation(0..3)` |
| Cores trocadas (negativo) | acrescente `tft.invertDisplay(false);` depois do `tft.init(...)` |
| Nenhuma porta aparece no PC | cabo USB só de carga, ou falta o driver CH340 / CP2102 |
| Monitor Serial não reage ao comando | terminação de linha não está em **Nova linha (NL)** |
| A placa reinicia ao abrir o Monitor Serial | normal no ESP8266 (DTR/RTS) |
| `mochi-serial.py` não abre a porta | Monitor Serial ou a ponte já rodando seguram a porta; ou falta `usermod -aG dialout $USER` |
| Arduino IDE não consegue gravar | a ponte (`mochi.service`) está segurando a porta — pare antes |
| Olhos cochilando com o Claude Code aberto | a ponte não está rodando, ou a `statusLine` não foi configurada |
| Status line vazia ou com erro no terminal | falta o `jq` |
| No modo Wi-Fi, `mochi.local` não responde | mDNS não atravessa a rede, ou o roteador tem isolamento de cliente — use o IP, ou volte para serial |

---

## Referências

- [`docs/PROTOBOARD.md`](PROTOBOARD.md) — as fases 1–5 em mais detalhe, focadas na bancada
- [`docs/tela/tela-mochi.svg`](tela/tela-mochi.svg) — todas as telas em escala 1:1, para saber o que esperar
- [`README.md`](../README.md) — por que a arquitetura é assim, e como escolher o display
- [`hardware/README.md`](../hardware/README.md) — o case alternativo (Pi Zero / Pico)

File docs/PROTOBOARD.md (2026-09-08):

# Montagem na protoboard

Guia para o primeiro teste, sem case e sem solda no circuito. A ideia é validar
o hardware **antes** de mexer em qualquer configuração do PC.

A ordem importa: cada passo só depende do anterior, então quando algo falhar
você sabe exatamente onde.

---

## 1. O que ter na mão

- ESP8266 (NodeMCU / Wemos D1 mini)
- Display ST7789 240×240 SPI, **com a barra de pinos já soldada**
- Jumpers fêmea-fêmea (ou macho-fêmea, se for usar a protoboard)
- Protoboard
- Cabo USB **com fios de dados**

Nada de resistor: os dois lados são 3,3 V.

> **Sobre a protoboard e a largura da placa.** Um NodeMCU v3 tem 31 mm e ocupa
> quase toda a protoboard padrão, sobrando **uma coluna livre de cada lado** —
> dá pra trabalhar, mas é apertado. O Wemos D1 mini (26 mm) deixa duas.
>
> Se ficar espremido, o caminho **ainda mais simples** é dispensar a protoboard
> nesta fase: jumpers fêmea-fêmea ligando direto os pinos do ESP nos pinos do
> display. São 7 ligações, e para um teste isso basta.

---

## 2. Ligações

<p align="center">
  Esquema das ligações na protoboard
</p>

**Confira duas vezes a linha VCC antes de energizar.** 5 V queima o display.

| Display | ESP8266 | Observação |
|---|---|---|
| GND | GND | |
| VCC | **3V3** | nunca 5 V / VIN |
| SCL (ou SCK) | D5 | GPIO14 — fixo, SPI por hardware |
| SDA (ou MOSI) | D7 | GPIO13 — fixo, SPI por hardware |
| RES (ou RST) | D2 | GPIO4 |
| DC | D1 | GPIO5 |
| BLK | **3V3** | backlight sempre aceso — o mais simples |
| CS | D8 | **só se o seu módulo tiver esse pino** |

São **7 ligações** (módulo de 7 pinos) ou **8** (módulo com CS).

Na protoboard, leve um jumper do `3V3` do ESP para a trilha **+** e um do `GND`
para a trilha **−**; daí saem os fios curtos de `VCC` e `BLK`.

Se o seu módulo **não tem CS**, abra o `.ino` e troque:

```c
#define TFT_CS   -1
```

Mantenha os jumpers curtos. Fio longo em SPI a 40 MHz gera ruído na imagem.

---

## 3. Passo 1 — só energia

Ligue o USB **sem gravar nada ainda**.

Esperado: a placa acende o LED e o **backlight do display acende** (tela branca
ou cinza uniforme, sem imagem — isso é normal, ainda não há firmware).

Se nada acender, ou se algo esquentar, tire da tomada e confira VCC/GND antes de
seguir.

---

## 4. Passo 2 — gravar e ver a animação

1. Arduino IDE → **Preferences → Additional Boards Manager URLs**:
   `https://arduino.esp8266.com/stable/package_esp8266com_index.json`
2. **Boards Manager** → *esp8266 by ESP8266 Community*
3. **Library Manager** → *Adafruit GFX Library* e *Adafruit ST7735 and ST7789 Library*
4. Abra `firmware/claude_mochi/claude_mochi.ino`, escolha a placa e a porta, grave.

**Esperado:** ao terminar a gravação, os olhos varrem de arregalados a
semicerrados e voltam, com a cor indo de verde a vermelho e a barra de baixo
enchendo — uns 3 segundos. Depois os olhos "cochilam" (traço fino), esperando o
PC.

**Se essa animação rodou, seu hardware está pronto.** Nada aqui depende de rede,
de status line ou de ponte serial.

---

## 5. Passo 3 — testar o protocolo pelo Monitor Serial

Ainda sem nenhuma configuração no Claude Code.

Abra o **Monitor Serial** da Arduino IDE e ajuste duas coisas:

- velocidade **115200**
- terminação de linha: **Nova linha (NL)**

> ⚠️ **É aqui que quase todo mundo trava.** O firmware só processa a linha
> quando recebe o `\n`. Se o Monitor Serial estiver em "Sem final de linha"
> (padrão em algumas versões), você digita, aperta enter e **não acontece
> absolutamente nada** — sem erro, sem pista.

Abrir o Monitor Serial reinicia a placa, então você verá a animação de boot de
novo. Normal.

Digite e envie:

```
ctx=20 win=10 state=idle
```

Os olhos devem abrir bem e ficar verdes; a placa responde `ok`. Agora teste os
extremos:

```
ctx=75 win=50 state=busy      -> olhos semicerrados, âmbar, piscando rápido
ctx=97 win=90 state=idle      -> olhos de tonto (X_X)
ctx=0  win=0  state=idle      -> volta ao normal
```

Pare de enviar por 30 segundos: ele volta a cochilar sozinho. Isso confirma o
timeout de "sem notícias do PC".

---

## 6. Passo 4 — ligar no Claude Code

Só agora vale mexer no PC. **Feche o Monitor Serial** — ele segura a porta e a
ponte não vai conseguir abrir.

```bash
pip install pyserial
cp host/statusline-mochi.sh ~/.claude/statusline-mochi.sh
cp host/mochi-mode.sh       ~/.claude/mochi-mode.sh
chmod +x ~/.claude/statusline-mochi.sh ~/.claude/mochi-mode.sh
./host/mochi-serial.py -v
```

Copie o bloco `statusLine` de `host/settings.example.json` para o seu
`~/.claude/settings.json` e abra o Claude Code numa outra aba. A cada mensagem
do assistente os olhos devem reagir.

O `-v` mostra cada linha enviada — útil na primeira vez.

---

## Quando algo dá errado

| Sintoma | Causa provável |
|---|---|
| Backlight aceso, tela branca, nunca aparece imagem | `RES` ou `DC` no pino errado; ou `#define TFT_CS D8` num módulo sem CS |
| Tela totalmente apagada | `BLK` sem 3,3 V, ou `VCC` sem contato |
| Imagem com listras, ruído ou pixels aleatórios | jumper longo demais; baixe `setSPISpeed` para `20000000` |
| Imagem de cabeça para baixo ou espelhada | ajuste `tft.setRotation(0..3)` |
| Cores trocadas (negativo) | acrescente `tft.invertDisplay(false);` depois do `tft.init(...)` |
| Nenhuma porta aparece no PC | cabo USB só de carga, ou falta o driver CH340 / CP2102 |
| Monitor Serial não reage ao comando | terminação de linha não está em **Nova linha (NL)** |
| A placa reinicia ao abrir o Monitor Serial | normal no ESP8266 (DTR/RTS) |
| `mochi-serial.py` não abre a porta | Monitor Serial ainda aberto; ou falta `usermod -aG dialout $USER` no Linux |
| Olhos cochilando com o Claude Code aberto | a ponte não está rodando, ou a `statusLine` não foi configurada |

---

Quando estiver funcionando na protoboard, aí sim vale medir tudo com paquímetro
e partir para o case (`case/mochi.scad`).

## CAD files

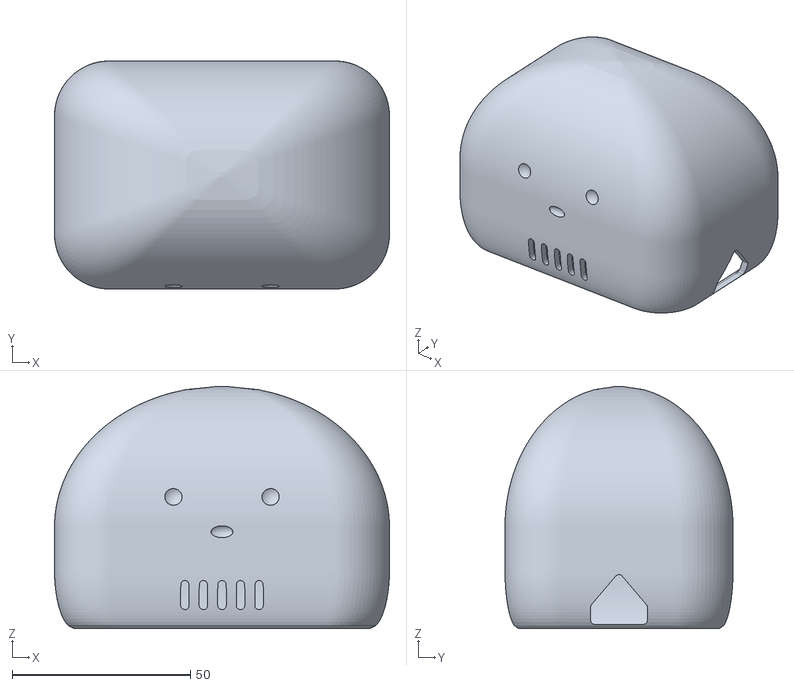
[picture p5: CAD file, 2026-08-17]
hardware/stl/pi_zero-casca.stl
94.0 x 64.0 x 68.0

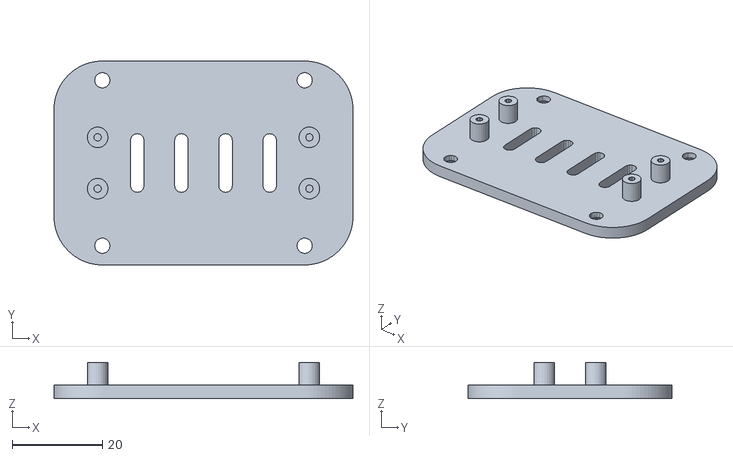
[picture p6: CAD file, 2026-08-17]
hardware/stl/pico-base.stl
66.4 x 45.3 x 8.00

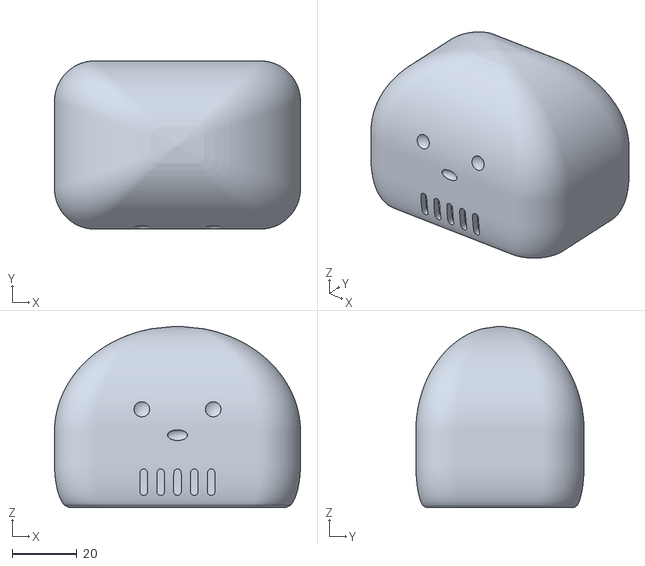
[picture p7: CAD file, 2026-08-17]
hardware/stl/pico-casca.stl
76.0 x 52.0 x 56.0

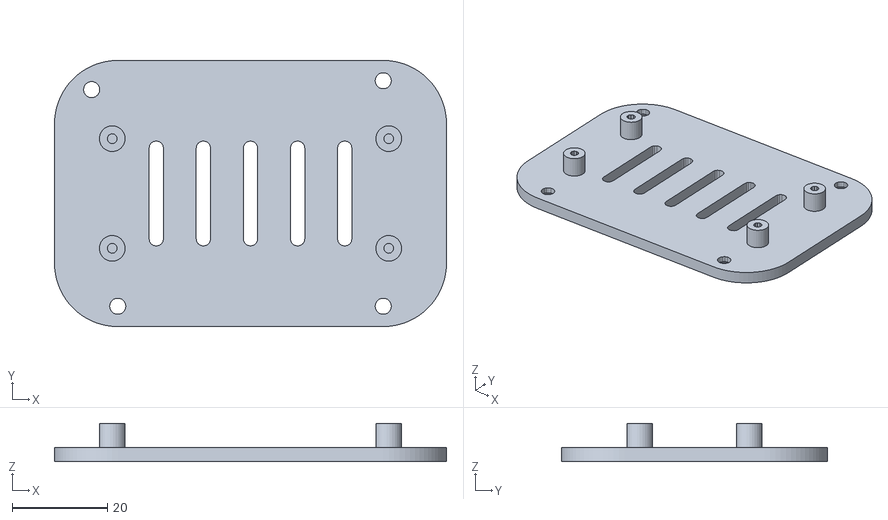
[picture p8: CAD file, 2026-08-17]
hardware/stl/pi_zero-base.stl
82.2 x 55.8 x 8.00

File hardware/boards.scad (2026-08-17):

// ---------------------------------------------------------------
//  claude-mochi / boards.scad
//  Especificacoes das placas suportadas.
// ---------------------------------------------------------------
//  Sistema de coordenadas local da placa (visto de cima):
//    origem = canto inferior-esquerdo do PCB
//    X = comprimento, Y = largura, Z = 0 na face inferior do PCB
//
//  Para adicionar uma placa nova basta acrescentar uma linha em
//  cada funcao abaixo usando o mesmo nome.
// ---------------------------------------------------------------

// [comprimento, largura, espessura do PCB]
function board_size(n) =
    n == "pi_zero" ? [65, 30, 1.2] :
    n == "pico"    ? [51, 21, 1.0] : undef;

// Centros dos furos de fixacao, em coordenadas locais.
function board_holes(n) =
    n == "pi_zero" ? [[3.5, 3.5], [61.5, 3.5], [3.5, 26.5], [61.5, 26.5]] :
    n == "pico"    ? [[2.0, 4.8], [49.0, 4.8], [2.0, 16.2], [49.0, 16.2]] : undef;

// Furo-guia do parafuso auto-atarraxante que prende a placa.
// pi_zero = M2.5, pico = M2.
function board_pilot(n) =
    n == "pi_zero" ? 2.1 :
    n == "pico"    ? 1.7 : undef;

// Raio externo do espacador impresso sob a placa.
function board_standoff_r(n) =
    n == "pi_zero" ? 2.7 :
    n == "pico"    ? 2.3 : undef;

// Aberturas na parede. Cada porta e:
//   [rotulo, [x, y] na borda do PCB, normal local, largura, altura,
//    z do centro em relacao ao TOPO do PCB]
function board_ports(n) =
    n == "pi_zero" ? [
        ["usb-pwr",   [54.0,  0], [ 0, -1], 13, 9,  3.0],
        ["usb-data",  [41.4,  0], [ 0, -1], 13, 9,  3.0],
        ["mini-hdmi", [12.4,  0], [ 0, -1], 14, 8,  3.0],
        ["microsd",   [ 0.0, 15], [-1,  0], 16, 6, -2.0]
    ] :
    n == "pico" ? [
        ["usb",       [ 0.0, 10.5], [-1, 0], 13, 9, 3.0]
    ] : undef;

// Portas abertas por padrao.
function board_open_ports(n) =
    n == "pi_zero" ? ["usb-pwr", "microsd"] :
    n == "pico"    ? ["usb"] : undef;

// Rotacao padrao da placa dentro da carcaca, em graus.
// Escolhida para o cabo de alimentacao sair por tras (pi_zero)
// ou pela lateral esquerda (pico).
function board_rot_default(n) =
    n == "pi_zero" ? 180 :
    n == "pico"    ? 0 : undef;

// Dimensoes externas sugeridas do corpo [largura, profundidade, altura].
function board_shell(n) =
    n == "pi_zero" ? [94, 64, 68] :
    n == "pico"    ? [76, 52, 56] : undef;

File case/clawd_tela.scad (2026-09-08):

// claude-mochi — Clawd com janela de display
// -----------------------------------------------------------------------------
// Base: as duas malhas do SEU projeto clawd_mochi.3mf (Bambu Studio), extraidas
// para models/upstream/3mf-corpo.stl e 3mf-chapa.stl. As duas ja vem centradas
// na origem, exatamente como o fatiador as tem.
//
// Origem da geometria: clawd-mochi de yousifamanuel — CC BY-NC-SA 4.0.
//
// O que este arquivo acrescenta ao modelo original:
//   1. janela para a area ativa do display, com chanfro de 45 graus
//   2. alargamento da cavidade em -Y, porque a placa do display nao cabia
//   3. moldura interna que segura a PCB contra a chapa, com saia a 45 graus
//      para imprimir SEM suporte nessa regiao
//
// So o DISPLAY vai dentro. O ESP8266 fica fora; os fios saem pelo fundo, que
// ja e aberto no modelo original.
//
// Gerar:
//   openscad -o chapa.stl -D 'part="chapa"' case/clawd_tela.scad
//   openscad -o corpo.stl -D 'part="corpo"' case/clawd_tela.scad
// -----------------------------------------------------------------------------

part = "montado";   // "chapa" | "corpo" | "montado" | "corte"

CORPO_STL = "../models/upstream/3mf-corpo.stl";
CHAPA_STL = "../models/upstream/3mf-chapa.stl";

$fn = 48;

// ------------------------------------------------------------------ escala ---
// Do seu 3mf: XY em 100%, e o corpo achatado em Z (38 -> 28 mm). O valor de Z
// e o m22 da matriz do objeto no arquivo. Como aqui a escala e assada na malha,
// no fatiador o objeto entra com escala 1 em Z.
escala_xy = 1.0;
escala_z  = 0.736842105;   // 28 / 38

// ----------------------------------------------------------------- display ---
// ⚠ MEDIDAS ESTIMADAS para um ST7789 1,54" 240x240 de 7 pinos.
// CONFIRA COM PAQUIMETRO antes de imprimir. O modulo entra deitado: o lado de
// 39 mm corre no eixo X.
pcb_x        = 39.0;   // lado maior da placa do display
pcb_y        = 31.5;   // lado menor
pcb_t        = 1.7;    // espessura da placa, sem componentes
ativa        = 27.7;   // lado da area ativa (quadrada)
ativa_dx     = -3.0;   // desvio da area ativa vs centro da placa, no eixo X
pcb_folga    = 0.30;   // folga por lado no encaixe da PCB
janela_folga = 0.40;   // quanto a janela abre alem da area ativa, por lado
chanfro      = 0.8;    // chanfro a 45 graus na borda externa da janela

// ------------------------------------------- contorno medido das malhas ------
// Levantado por amostragem sobre as malhas do 3mf; nao mexa sem remedir.
larg     = 63.94;   // X das duas pecas
prof     = 48.62;   // Y das duas pecas
corpo_h  = 38.00;   // altura do corpo na malha, ANTES de escala_z
chapa_h  =  2.00;

cav_x0   = -24.25;  cav_x1 = 24.25;   // cavidade passante, em X
cav_y0   = -10.75;  cav_y1 = 21.50;   // em Y  (parede -Y tem 13,56 mm; +Y so 2,81)

boca_cy  = -7.62;   boca_l = 9.00;  boca_a = 3.25;   // furo da boca, na chapa
olho_dx  = 29.25;   olho_cy = 5.50; olho_l = 3.50;   // os dois furinhos das orelhas

// ------------------------------------------------------------------ extras ---
// A cavidade tem 32,25 mm em Y e a placa do display tem 31,5: sobram 0,375 mm
// por lado. Aperta, mas alargar em -Y NAO e de graca: em Y -10,75..-12,5 existe
// uma faixa macica que fecha o fundo da cavidade e de onde saem as quatro
// perninhas. Cortar a faixa inteira solta as perninhas do corpo (foi o que deu
// "Volumes: 3" na primeira tentativa). Por isso o alargamento e opcional e so
// vale para os primeiros milimetros a partir do topo, onde a PCB realmente esta.
alargar    = 0.0;    // 0 = cavidade original. >0 come a faixa do fundo.
alargar_z  = 3.0;    // profundidade do alargamento, medida a partir do topo

moldura    = true;   // moldura interna que segura a PCB contra a chapa
moldura_t  = 2.0;    // espessura da moldura
tapar_boca = true;   // a boca cai dentro da janela; sem tapar vira rebarba

// --------------------------------------------------------------- derivados ---
corpo_hz = corpo_h * escala_z;          // altura real do corpo depois de achatado
corpo_z0 = -corpo_hz / 2;               // a malha e centrada em Z
corpo_z1 =  corpo_hz / 2;

cav_l  = (cav_x1 - cav_x0) * escala_xy;                 // cavidade em X
cav_p  = (cav_y1 - (cav_y0 - alargar)) * escala_xy;     // em Y, com o alargamento
cav_cx = (cav_x0 + cav_x1) / 2 * escala_xy;
cav_cy = ((cav_y0 - alargar) + cav_y1) / 2 * escala_xy;

pcb_lx = pcb_x + 2 * pcb_folga;
pcb_ly = pcb_y + 2 * pcb_folga;

// A moldura fica ATRAS da PCB e a empurra contra a chapa. A abertura dela e a
// mesma da janela: menor que a placa (senao a placa passa direto por dentro) e
// nao menor que a area ativa (senao apareceria tapando a borda da tela).
mold_l = ativa + 2*janela_folga;
mold_p = ativa + 2*janela_folga;

// quanto de borda da PCB a moldura pega, dos quatro lados
pega_xm = (pcb_x/2) - (mold_l/2 - ativa_dx);
pega_xp = (pcb_x/2) - (mold_l/2 + ativa_dx);
pega_ym = (pcb_y - mold_p) / 2;

// saia a 45 graus embaixo da moldura, para nao precisar de suporte
recuo    = max((cav_l + 1.2 - mold_l) / 2, (cav_p + 1.2 - mold_p) / 2);
mold_z1  = corpo_z1 - pcb_t;             // topo da moldura
mold_z0  = mold_z1 - moldura_t;          // base da parte reta
saia_z0  = mold_z0 - recuo;              // onde a saia comeca

// ------------------------------------------------------------- verificacoes --
assert(pcb_lx <= cav_l,
       str("A placa nao entra no eixo X: precisa de ", pcb_lx,
           " mm e a cavidade tem ", cav_l, " mm. Aumente 'escala_xy'."));
assert(pcb_ly <= cav_p,
       str("A placa nao entra no eixo Y: precisa de ", pcb_ly,
           " mm e a cavidade tem ", cav_p,
           " mm. Aumente 'alargar' (a parede -Y tem 13,56 mm) ou 'escala_xy'."));
assert(cav_y0 - alargar > -prof/2 + 3.0,
       str("'alargar' = ", alargar,
           " deixaria a parede -Y com menos de 3 mm. Reduza."));
assert(saia_z0 > corpo_z0 + 1.0,
       "A moldura com a saia de 45 graus nao cabe na altura do corpo. Reduza 'moldura_t' ou aumente 'escala_z'.");
assert(ativa + 2*janela_folga < pcb_y,
       "A janela ficou maior que a placa — reveja 'ativa' e 'janela_folga'.");
assert(min(pega_xm, pega_xp, pega_ym) >= 1.0,
       str("A moldura so pegaria ", min(pega_xm, pega_xp, pega_ym),
           " mm de borda da PCB (minimo 1,0). Reduza 'janela_folga' ou reveja ",
           "'ativa_dx'."));

jan_cx = cav_cx + ativa_dx;
jan_cy = cav_cy;

// ------------------------------------------------------------------ pecas ----
module corpo_bruto() { scale([escala_xy, escala_xy, escala_z]) import(CORPO_STL, convexity = 10); }
module chapa_bruta() { scale([escala_xy, escala_xy, 1])        import(CHAPA_STL, convexity = 10); }

// Alargamento da cavidade para -Y, so nos 'alargar_z' mm de cima. Assim a faixa
// macica do fundo e as perninhas continuam inteiras abaixo do corte.
module alargamento() {
    if (alargar > 0)
        translate([cav_cx, (cav_y0 - alargar/2) * escala_xy, corpo_z1 - alargar_z/2 + 0.01])
            cube([(cav_x1 - cav_x0) * escala_xy, alargar * escala_xy, alargar_z], center = true);
}

// janela quadrada com chanfro a 45 graus na face de fora (+Z)
module janela(h) {
    j = ativa + 2*janela_folga;
    union() {
        translate([0, 0, 0]) cube([j, j, h + 4], center = true);
        if (chanfro > 0)
            translate([0, 0, h/2 - chanfro])
                linear_extrude(height = chanfro + 0.01, scale = (j + 2*chanfro) / j)
                    square([j, j], center = true);
    }
}

module chapa() {
    difference() {
        union() {
            chapa_bruta();
            // A base da janela cai dentro da boca e deixaria uma fresta de
            // 0,37 mm. A tampa desce ate bem dentro do macico da chapa, senao
            // o chanfro descola a lasca e ela sai como solido solto no STL.
            // Altura exatamente igual a da chapa: sobrando em Z, vira degrau
            // na face de fora.
            if (tapar_boca)
                translate([0, (boca_cy - 2.25) * escala_xy, 0])
                    cube([(boca_l + 0.6) * escala_xy, (boca_a + 5.1) * escala_xy,
                          chapa_h], center = true);
        }
        translate([jan_cx, jan_cy, 0]) janela(chapa_h);
    }
}
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

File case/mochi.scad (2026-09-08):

// claude-mochi — case paramétrico
// -----------------------------------------------------------------------------
// v0: ponto de partida. TODAS as medidas de componente abaixo precisam ser
// conferidas com paquímetro no SEU display e na SUA placa antes de imprimir.
//
// Como gerar os STLs (linha de comando):
//   openscad -D 'part="front"' -o front.stl mochi.scad
//   openscad -D 'part="back"'  -o back.stl  mochi.scad
//
// Ou abra no OpenSCAD e mude a variável `part` no topo.
// -----------------------------------------------------------------------------

part = "all";   // "all" | "front" | "back" | "preview"

$fn = 64;

// ---------------------------------------------------------------- display ---
// ST7789 1.54" 240x240, módulo de 7 pinos. CONFIRA COM PAQUÍMETRO.
scr_pcb_w      = 31.5;  // largura da placa do display
scr_pcb_h      = 39.0;  // altura da placa do display
scr_pcb_t      = 1.7;   // espessura da placa (sem componentes)
scr_active     = 27.7;  // lado da área ativa (quadrada)
scr_active_dy  = -3.0;  // deslocamento vertical da área ativa vs centro da placa
scr_fit        = 0.35;  // folga por lado no encaixe da placa

// ------------------------------------------------------------------ placa ---
// Wemos D1 mini: 34.2 x 25.6 | NodeMCU v3: 58 x 31 | NodeMCU v2: 49 x 26
brd_l          = 34.2;
brd_w          = 25.6;
brd_t          = 1.4;
brd_fit        = 0.4;

// Só o display vai dentro do mochi: o ESP8266 fica de fora, ligado por jumpers
// (é a montagem de docs/PROTOBOARD.md). Nesse modo a prateleira da placa e o
// recorte do USB não são gerados — entra no lugar uma saída para o chicote.
so_display     = true;
cabo_w         = 12.0;  // largura da saída dos jumpers na traseira
cabo_h         = 5.0;   // altura
cabo_z         = 10.0;  // altura do centro a partir da base

// Recorte do conector USB (micro-USB na maioria dos ESP8266).
// Só usado quando so_display = false.
usb_w          = 9.0;
usb_h          = 4.0;
usb_z          = 12.0;  // altura do centro do conector a partir da base

// ------------------------------------------------------------------ corpo ---
wall           = 2.2;   // espessura de parede
body_w         = 78;    // largura total
body_d         = 62;    // profundidade total
body_h         = 70;    // altura total
r_bot          = 17;    // raio das esferas da base
r_mid          = 19;    // raio da "barriga"
r_top          = 21;    // raio da cúpula
top_scale      = 0.36;  // quão estreito é o topo (fração da largura)

face_y         = 23.0;  // plano do rosto: face plana em y = -face_y
split_y        = 6.0;   // plano de separação frente/tampa (y = +split_y)
lip_h          = 3.0;   // altura do lábio de encaixe da tampa
lip_fit        = 0.30;  // folga do lábio
lip_t          = 1.4;   // espessura radial do lábio
lip_weld       = 0.8;   // quanto o lábio invade a metade frontal, em y e em
                        // raio. Sem isso ele encosta na casca só por uma face
                        // coincidente e sai como um anel solto no STL.

// Bossas de parafuso M2 (para inserto ou parafuso auto-atarraxante).
boss_r         = 3.2;
boss_hole      = 1.7;   // 1.7 p/ auto-atarraxante M2; 3.2 p/ inserto térmico M2
boss_dx        = 26;    // distância horizontal entre bossas (a partir do centro)
boss_dz        = 0;     // altura das bossas relativa ao centro do rosto

face_cz        = body_h * 0.60;  // centro do rosto (altura do display)

// =============================================================================
// Geometria do corpo
// =============================================================================
// O corpo é o casco convexo (hull) de 12 esferas em 3 "andares". Como o
// resultado é um hull de esferas, dá para obter o offset interno EXATO só
// reduzindo o raio de cada esfera em `wall` — sem minkowski (que é lentíssimo).

lobes = [
  // [ meia-largura x, meia-profundidade y, z do centro, raio ]
  [ body_w/2 - r_bot, body_d/2 - r_bot, r_bot * 0.72,          r_bot ],
  [ body_w/2 - r_mid, body_d/2 - r_mid, body_h * 0.44,         r_mid ],
  [ body_w * top_scale - r_top, body_d * top_scale - r_top,
                                        body_h - r_top,        r_top ]
];

module body_solid(grow = 0) {
  hull()
    for (l = lobes)
      for (sx = [-1, 1])
        for (sy = [-1, 1])
          translate([sx * max(l[0], 0.01), sy * max(l[1], 0.01), l[2]])
            sphere(r = l[3] + grow);
}

// Corpo com a base achatada e o rosto plano na frente (-Y).
module body_shaped(grow = 0) {
  difference() {
    body_solid(grow);
    translate([0, 0, -100]) cube([400, 400, 200], center = true);              // base
    translate([0, -200 - (face_y + grow), 0]) cube([400, 400, 400], center = true); // rosto
  }
}

module body_shell() {
  difference() {
    body_shaped(0);
    body_shaped(-wall);
  }
}

// =============================================================================
// Recortes e detalhes
// =============================================================================

// Janela do display: rasgo passante da área ativa + rebaixo para a placa.
module screen_cutouts() {
  // Rasgo passante (área ativa), com leve chanfro para a luz não "vinhetar".
  translate([0, -face_y - 1, face_cz + scr_active_dy])
    rotate([90, 0, 0])
      linear_extrude(height = wall + 3, center = false, scale = 0.94)
        square([scr_active + 1.0, scr_active + 1.0], center = true);

  // Rebaixo para a placa do display, por dentro.
  translate([0, -face_y + wall/2, face_cz])
    cube([scr_pcb_w + 2*scr_fit, wall + 2.2, scr_pcb_h + 2*scr_fit], center = true);
}

// Recorte do USB, no fundo da tampa traseira.
module usb_cutout() {
  translate([0, body_d/2, usb_z])
    rotate([90, 0, 0])
      linear_extrude(height = 30, center = true)
        offset(r = 1)
          square([usb_w - 2, usb_h - 2], center = true);
}

// Saída do chicote de jumpers, no fundo da tampa traseira (so_display = true).
// Mais larga e mais baixa que o recorte de USB: passam 7 ou 8 fios juntos.
module cable_slot() {
  translate([0, body_d/2, cabo_z])
    rotate([90, 0, 0])
      linear_extrude(height = 30, center = true)
        offset(r = 1.5)
          square([max(cabo_w - 3, 0.1), max(cabo_h - 3, 0.1)], center = true);
}

// Furos de ventilação discretos na base (o backlight esquenta um pouco).
module vents() {
  for (i = [-2 : 2])
    translate([i * 7, 0, -1])
      cylinder(r = 1.6, h = 8);
}

// Bossas de parafuso para prender o display, atrás do rosto.
module screen_bosses() {
  for (sx = [-1, 1])
    translate([sx * boss_dx/2, -face_y + wall, face_cz + boss_dz])
      rotate([-90, 0, 0])
        difference() {
          cylinder(r = boss_r, h = 5);
          translate([0, 0, -0.5]) cylinder(r = boss_hole/2, h = 6.5);
        }
}

// Duas abas onde as bordas da placa do ESP encostam (a fita dupla face vai
// aqui). Cada aba nasce na parede lateral e avança 3 mm por baixo da placa.
// Um trilho solto no meio da cavidade — sem tocar parede nenhuma — sairia
// como peça separada no STL.
module board_shelf() {
  shelf_w = brd_w + 2 * brd_fit;   // largura ocupada pela placa
  intersection() {
    body_shaped(-wall + lip_weld);        // morde a parede dos dois lados
    difference() {
      translate([0, split_y - 6, 14]) cube([2 * body_w, 3, 2], center = true);
      translate([0, split_y - 6, 14]) cube([shelf_w - 6, 5, 4], center = true);
    }
  }
}

// Lábio de encaixe. São duas faixas em y, e a diferença entre elas é o que
// mantém a peça inteira:
//   y > split_y  entra na tampa, rebaixado lip_fit para deslizar;
//   y < split_y  invade a metade frontal e morde a parede por lip_weld.
module lip() {
  // trecho que entra na tampa
  intersection() {
    difference() {
      body_shaped(-wall - lip_fit);
      body_shaped(-wall - lip_fit - lip_t);
    }
    translate([0, split_y + lip_h/2, 200])
      cube([400, lip_h, 400], center = true);
  }
  // trecho de solda, já dentro da metade frontal
  intersection() {
    difference() {
      body_shaped(-wall + lip_weld);
      body_shaped(-wall - lip_fit - lip_t);
    }
    translate([0, split_y - lip_weld/2, 200])
      cube([400, lip_weld, 400], center = true);
  }
}

// Bolsa da tampa que recebe o lábio. Tira só a faixa interna: a parede
// externa da tampa continua descendo até o plano de corte, senão a caixa
// montada fica com um vinco aberto de lip_h em toda a volta.
module lip_pocket() {
  intersection() {
    difference() {
      body_shaped(-wall);
      body_shaped(-wall - lip_fit - lip_t - 0.2);
    }
    translate([0, split_y + lip_h/2, 200])
      cube([400, lip_h + 0.4, 400], center = true);
  }
}

// =============================================================================
// Partes
// =============================================================================
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

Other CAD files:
hardware/mochi.scad

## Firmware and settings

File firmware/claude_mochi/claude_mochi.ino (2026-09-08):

// claude-mochi — olhos que indicam o consumo de tokens do Claude Code.
// Por padrao os olhos E a barra seguem o LIMITE DE 5 HORAS.
// Troque em OLHOS_METRICA / BARRA_METRICA.
//
// Placa   : ESP8266 (NodeMCU / Wemos D1 mini / ESP-12)
// Display : ST7789 1.54" 240x240 SPI (modulo de 7 pinos, com CS)
//
// DOIS MODOS DE LIGACAO (escolha um abaixo em LINK_SERIAL / LINK_WIFI):
//
//   Serial (padrao, recomendado)
//     O PC manda linhas pela USB: "ctx=42 win=63 state=busy\n".
//     Nao precisa de rede nenhuma. Funciona em Wi-Fi corporativo,
//     em rede de visitante, ou totalmente offline. A pilha Wi-Fi nem
//     sobe, entao sobra RAM para o display.
//     Do lado do PC quem fala com a porta e host/mochi-serial.py.
//
//   Wi-Fi
//     O ESP entra na sua rede como cliente e expoe um endpoint HTTP.
//     So use se o PC e o mochi estiverem na MESMA rede e o roteador
//     nao tiver isolamento de cliente (a maioria das redes de empresa
//     tem, e ai isso nao funciona).
//
// Protocolo serial: uma linha por atualizacao, pares chave=valor
// separados por espaco, terminada em \n. Chaves aceitas: ctx, win, state.

#define LINK_SERIAL 1
#define LINK_WIFI   0

#include <Adafruit_GFX.h>
#include <Adafruit_ST7789.h>
#include <SPI.h>

// ESP8266WiFi.h entra nos DOIS modos: no modo serial o setup() ainda chama
// WiFi.mode(WIFI_OFF) / forceSleepBegin() para desligar o radio.
#include <ESP8266WiFi.h>

#if LINK_WIFI
  #include <ESP8266WebServer.h>
  #include <ESP8266mDNS.h>
  #include "config.h"      // copie de config.example.h (so precisa no modo Wi-Fi)
  ESP8266WebServer server(80);
#endif

// ---------------------------------------------------------------- pinagem ---
// Labels D* sao do NodeMCU / Wemos D1 mini. SCK e MOSI sao fixos no HW SPI.
//
// TFT_CS: os modulos ST7789 240x240 vem em duas variantes.
//   8 pinos -> tem CS: deixe D8 como esta e ligue o fio.
//   7 pinos -> NAO tem CS (fica em GND internamente): troque para -1
//              e nao ligue fio nenhum. Um pino livre de brinde.
// As duas funcionam: o display e o unico dispositivo no barramento SPI.
#define TFT_CS   D8   // GPIO15 — use -1 se o seu modulo nao tiver pino CS
#define TFT_DC   D1   // GPIO5
#define TFT_RST  D2   // GPIO4
// SCK  -> D5 (GPIO14)
// MOSI -> D7 (GPIO13)

// Backlight. O jeito mais simples e ligar BLK direto no 3V3 e deixar
// USE_BLK_PIN em 0 — um fio a menos e nada para dar errado. Coloque 1 se
// quiser controlar o brilho por software (ai ligue BLK no pino abaixo).
#define USE_BLK_PIN 0
#define TFT_BLK  D6   // GPIO12 (so usado se USE_BLK_PIN for 1)

// Animacao de boot: varre o contexto de 0 a 100% e volta, logo ao ligar.
// Serve para validar display e fiacao na protoboard SEM depender do PC.
#define BOOT_DEMO 1

Adafruit_ST7789 tft = Adafruit_ST7789(TFT_CS, TFT_DC, TFT_RST);

// ------------------------------------------------------------------ cores ---
static const uint16_t C_FACE   = 0xFB26;  // laranja forte, o "rosto" do mochi (#FF6633)
// Matiz do clay da Anthropic (#D97757, H 15) mas com saturacao 100%. O clay
// puro tem so 63% de saturacao e sai lavado num painel retroiluminado.
// Outras opcoes do mesmo matiz: 0xFAE3 (#FF5E1A, mais forte),
// 0xFB63 (#FF6E1A, mais amarelado), 0xDBAA (#D97757, o clay original).
static const uint16_t C_EYE    = 0x18E3;  // quase preto
static const uint16_t C_OK     = 0x2E88;  // verde
static const uint16_t C_WARN   = 0xFCA0;  // ambar
static const uint16_t C_HOT    = 0xE0A3;  // vermelho
static const uint16_t C_SHINE  = 0xFFFF;  // brilho do olho
static const uint16_t C_TRACK  = 0x8A44;  // trilho da barra, laranja escuro (#8A4A22)
static const uint16_t C_SLEEP  = 0xD69A;  // olhos "dormindo" (sem dados)

// --------------------------------------------------------------- geometria ---
static const int16_t SCR       = 240;
static const int16_t EYE_CX_L  = 72;
static const int16_t EYE_CX_R  = 168;
static const int16_t EYE_CY    = 104;
static const int16_t EYE_RX    = 36;   // meia-largura do olho
static const int16_t EYE_RY    = 42;   // meia-altura maxima do olho
// A area que drawEye limpa e (EYE_RX+4)*2 por (EYE_RY+4)*2. Com os valores
// acima isso ocupa x 32..112 e 128..208, e y 58..150 — sem invadir a borda
// nem a barra (y 206). Se aumentar mais, confira essas contas antes.
static const int16_t BAR_Y     = 206;
static const int16_t BAR_H     = 10;
static const int16_t BAR_X     = 34;
static const int16_t BAR_W     = SCR - 2 * BAR_X;

// Sem noticias do PC por este tempo -> o mochi "cochila".
static const unsigned long IDLE_TIMEOUT_MS = 30000;

// ------------------------------------------------------------------ estado ---
struct State {
  int   ctx       = 0;       // % da janela de contexto usada
  int   win       = 0;       // % do limite de 5h usado
  char  mode[12]  = "idle";  // idle | busy | compact
  bool  backlight = true;
  unsigned long lastPing = 0;
  bool  everPinged = false;
} st;

// -------------------------------------------------- o que a tela esta medindo ---
// Cada elemento escolhe sua metrica, de forma independente:
//   1 -> limite de 5 horas (st.win)
//   0 -> janela de contexto (st.ctx)
//
// Padrao: os DOIS no limite de 5h. Olhos e barra concordam sempre na cor, e a
// barra da o numero exato que a abertura da palpebra so sugere. A janela de
// contexto deixa de aparecer na tela — o firmware ainda aceita "ctx=" no
// protocolo, so nao desenha nada com ele.
//
// O limite de 5h anda MUITO mais devagar que o contexto e zera a cada janela,
// entao o mochi fica bem menos agitado assim. E de proposito: ele mede quanto
// da sua cota ja foi, nao quanto o chat cresceu.
#define OLHOS_METRICA 1
#define BARRA_METRICA 1

#if OLHOS_METRICA
  #define VAL_OLHOS (st.win)
#else
  #define VAL_OLHOS (st.ctx)
#endif

#if BARRA_METRICA
  #define VAL_BARRA (st.win)
#else
  #define VAL_BARRA (st.ctx)
#endif

static float  openNow    = 1.0f;   // abertura atual da palpebra (animada)
static float  openTarget = 1.0f;
static bool   blinking   = false;
static unsigned long blinkUntil = 0;
static unsigned long nextBlink  = 0;
static int    lastDrawnOlhos = -1;
static int    lastDrawnBarra = -1;
static int    lastEyeH     = -1;
static bool   lastCrossed  = false;
static bool   lastAsleep   = false;

// ------------------------------------------------------------------- utils ---
static int clampi(int v, int lo, int hi) { return v < lo ? lo : (v > hi ? hi : v); }

// Mistura duas cores RGB565 com fator t em [0,1].
static uint16_t mix(uint16_t a, uint16_t b, float t) {
  if (t < 0) t = 0;
  if (t > 1) t = 1;
  int ar = (a >> 11) & 0x1F, ag = (a >> 5) & 0x3F, ab = a & 0x1F;
  int br = (b >> 11) & 0x1F, bg = (b >> 5) & 0x3F, bb = b & 0x1F;
  int r  = ar + (int)((br - ar) * t);
  int g  = ag + (int)((bg - ag) * t);
  int bl = ab + (int)((bb - ab) * t);
  return (uint16_t)((r << 11) | (g << 5) | bl);
}

// Verde -> ambar -> vermelho conforme a porcentagem.
static uint16_t levelColor(int pct) {
  if (pct <= 60) return mix(C_OK, C_WARN, pct / 60.0f);
  return mix(C_WARN, C_HOT, (pct - 60) / 40.0f);
}

static bool isAsleep() {
  return !st.everPinged || (millis() - st.lastPing > IDLE_TIMEOUT_MS);
}

// ------------------------------------------------------------------ desenho ---

// Elipse cheia. O Adafruit_GFX so tem circulo, entao desenhamos por linhas.
static void fillEllipse(int16_t cx, int16_t cy, int16_t rx, int16_t ry, uint16_t color) {
  if (rx <= 0 || ry <= 0) return;
  for (int16_t dy = -ry; dy <= ry; dy++) {
    float k = 1.0f - (float)(dy * dy) / (float)(ry * ry);
    if (k < 0) k = 0;
    int16_t dx = (int16_t)(rx * sqrtf(k));
    if (dx > 0) tft.drawFastHLine(cx - dx, cy + dy, dx * 2, color);
  }
}

// Olho "tonto": um X, para a metrica dos olhos estourando ou compactacao.
static void drawCrossEye(int16_t cx, int16_t cy, uint16_t color) {
  const int16_t r = 28;
  for (int16_t o = -2; o <= 2; o++) {
    tft.drawLine(cx - r, cy - r + o, cx + r, cy + r + o, color);
    tft.drawLine(cx - r, cy + r + o, cx + r, cy - r + o, color);
  }
}

static void drawEye(int16_t cx, int16_t cy, int16_t ry, uint16_t iris,
                    bool crossed, bool asleep) {
  // Limpa apenas a area do olho (evita redesenhar a tela toda = sem flicker).
  tft.fillRect(cx - EYE_RX - 4, cy - EYE_RY - 4,
               (EYE_RX + 4) * 2, (EYE_RY + 4) * 2, C_FACE);

  if (asleep) {
    // Sem dados do PC: olhos fechados, tracinho suave.
    tft.fillRoundRect(cx - EYE_RX + 4, cy - 2, (EYE_RX - 4) * 2, 5, 2, C_SLEEP);
    return;
  }

  if (crossed) { drawCrossEye(cx, cy, C_EYE); return; }

  if (ry < 3) {
    tft.fillRoundRect(cx - EYE_RX, cy - 2, EYE_RX * 2, 5, 2, C_EYE);
    return;
  }

  fillEllipse(cx, cy, EYE_RX, ry, C_EYE);

  // Iris colorida pelo nivel, proporcional a abertura.
  int16_t irx = EYE_RX * 0.55f;
  int16_t iry = ry * 0.55f;
  if (iry >= 2) fillEllipse(cx, cy, irx, iry, iris);

  if (ry > EYE_RY * 0.45f) {
    tft.fillCircle(cx - EYE_RX / 3, cy - ry / 2, 5, C_SHINE);
  }
}

// Barra inferior = limite de 5 horas.
static void drawBar(int pct) {
  tft.fillRoundRect(BAR_X, BAR_Y, BAR_W, BAR_H, BAR_H / 2, C_TRACK);
  int w = (BAR_W * clampi(pct, 0, 100)) / 100;
  if (w >= BAR_H) {
    tft.fillRoundRect(BAR_X, BAR_Y, w, BAR_H, BAR_H / 2, levelColor(pct));
  } else if (w > 0) {
    tft.fillRect(BAR_X, BAR_Y, w, BAR_H, levelColor(pct));
  }
}

#if BOOT_DEMO
// Varre 0 -> 100 -> 0% de contexto ao ligar. Se isto animar, display e
// fiacao estao corretos; nada disso depende do PC ou da rede.
static void bootDemo() {
  for (int step = 0; step <= 200; step += 4) {
    const int      pct  = (step <= 100) ? step : (200 - step);
    const float    open = 1.0f - 0.72f * (pct / 100.0f);
    const int16_t  h    = (int16_t)(EYE_RY * open);
    const uint16_t iris = levelColor(pct);
    drawEye(EYE_CX_L, EYE_CY, h, iris, false, false);
    drawEye(EYE_CX_R, EYE_CY, h, iris, false, false);
    drawBar(pct);
    delay(10);
  }
  // Termina no estado "cochilando", esperando o PC.
  drawEye(EYE_CX_L, EYE_CY, 0, C_EYE, false, true);
  drawEye(EYE_CX_R, EYE_CY, 0, C_EYE, false, true);
  drawBar(0);
}
#endif

// =============================================================== ligacao ====

// Aplica um par "chave=valor".
static void applyKV(char *kv) {
  char *eq = strchr(kv, '=');
  if (!eq) return;
  *eq = '\0';
  const char *k = kv;
  const char *v = eq + 1;
  if      (!strcmp(k, "ctx"))   st.ctx = clampi(atoi(v), 0, 100);
  else if (!strcmp(k, "win"))   st.win = clampi(atoi(v), 0, 100);
  else if (!strcmp(k, "state")) {
    strncpy(st.mode, v, sizeof(st.mode) - 1);
    st.mode[sizeof(st.mode) - 1] = '\0';
  }
}

// Aplica uma linha inteira: "ctx=42 win=63 state=busy".
static void applyLine(char *line) {
  for (char *tok = strtok(line, " \t"); tok; tok = strtok(NULL, " \t")) applyKV(tok);
  st.lastPing = millis();
  st.everPinged = true;
}

#if LINK_SERIAL
static char    rxbuf[96];
static uint8_t rxlen = 0;

static void pollSerial() {
  while (Serial.available()) {
    char c = (char)Serial.read();
    if (c == '\n' || c == '\r') {
      if (rxlen) {
        rxbuf[rxlen] = '\0';
        applyLine(rxbuf);
        rxlen = 0;
        Serial.println("ok");   // eco para a ponte saber que estamos vivos
      }
    } else if (rxlen < sizeof(rxbuf) - 1) {
      rxbuf[rxlen++] = c;
    } else {
      rxlen = 0;               // linha absurda: descarta
    }
  }
}
#endif

#if LINK_WIFI
static void handleTokens() {
  char line[96];
  snprintf(line, sizeof(line), "ctx=%s win=%s state=%s",
           server.hasArg("ctx")   ? server.arg("ctx").c_str()   : "",
           server.hasArg("win")   ? server.arg("win").c_str()   : "",
           server.hasArg("state") ? server.arg("state").c_str() : "");
  applyLine(line);
  server.send(200, "text/plain", "ok");
}

static void handleState() {
  char buf[176];
  snprintf(buf, sizeof(buf),
           "{\"ctx\":%d,\"win\":%d,\"mode\":\"%s\",\"backlight\":%s,\"uptime_s\":%lu}",
           st.ctx, st.win, st.mode, st.backlight ? "true" : "false", millis() / 1000);
  server.send(200, "application/json", buf);
}

static void handleBacklight() {
  st.backlight = server.arg("on") != "0";
#if USE_BLK_PIN
  analogWrite(TFT_BLK, st.backlight ? 1023 : 0);
#endif
  server.send(200, "text/plain", "ok");
}

static void handleRoot() {
  char buf[420];
  snprintf(buf, sizeof(buf),
           "<!doctype html><meta name=viewport content='width=device-width'>"
           "<body style='font-family:system-ui;background:#14110f;color:#f4f1ea;padding:24px'>"
           "<h2>claude-mochi</h2><p>contexto: <b>%d%%</b><br>limite 5h: <b>%d%%</b><br>"
           "modo: <b>%s</b><br>ip: %s</p></body>",
           st.ctx, st.win, st.mode, WiFi.localIP().toString().c_str());
  server.send(200, "text/html", buf);
}

static void startWifi() {
  tft.setTextColor(C_EYE);
  tft.setTextSize(2);
  tft.setCursor(20, 100);
  tft.print("conectando");

  WiFi.mode(WIFI_STA);
  WiFi.hostname(MDNS_NAME);
  WiFi.begin(WIFI_SSID, WIFI_PASSWORD);
  for (int i = 0; i < 80 && WiFi.status() != WL_CONNECTED; i++) delay(250);

  tft.fillScreen(C_FACE);
  tft.setTextSize(1);
  tft.setCursor(10, 90);
  if (WiFi.status() == WL_CONNECTED) {
    tft.print("http://"); tft.print(MDNS_NAME); tft.println(".local");
    tft.setCursor(10, 106);
    tft.print(WiFi.localIP());
    if (MDNS.begin(MDNS_NAME)) MDNS.addService("http", "tcp", 80);
  } else {
    tft.print("wifi falhou - confira config.h");
  }
  delay(2500);

  server.on("/", handleRoot);
  server.on("/tokens", handleTokens);
  server.on("/state", handleState);
  server.on("/backlight", handleBacklight);
  server.begin();
}
#endif

// ------------------------------------------------------------------ setup ---

void setup() {
  Serial.begin(115200);

#if USE_BLK_PIN
  pinMode(TFT_BLK, OUTPUT);
  analogWrite(TFT_BLK, 1023);
#endif

  tft.init(240, 240);
  tft.setSPISpeed(40000000);  // se a imagem sair com ruido, baixe para 20000000
  tft.setRotation(1);         // ajuste 0..3 conforme a orientacao do seu modulo
  tft.fillScreen(C_FACE);

#if BOOT_DEMO
  bootDemo();
#endif

#if LINK_WIFI
  startWifi();
#endif

#if LINK_SERIAL && !LINK_WIFI
  // Sem Wi-Fi: desliga o radio de vez. Economiza ~20 mA e libera RAM.
  WiFi.mode(WIFI_OFF);
  WiFi.forceSleepBegin();
  delay(1);
  Serial.println("mochi pronto");
#endif

  randomSeed(micros());
  nextBlink = millis() + 3000;
}

// ------------------------------------------------------------------- loop ---

void loop() {
#if LINK_SERIAL
  pollSerial();
#endif
#if LINK_WIFI
  server.handleClient();
  MDNS.update();
#endif

  const unsigned long now = millis();
  const bool asleep = isAsleep();

  // Piscar: mais rapido enquanto o Claude esta trabalhando.
  const bool busy = (strcmp(st.mode, "busy") == 0);
  if (!blinking && now >= nextBlink) {
    blinking = true;
    blinkUntil = now + 110;
  }
  if (blinking && now >= blinkUntil) {
    blinking = false;
    nextBlink = now + (busy ? random(900, 2000) : random(2800, 6000));
  }

  // Alvo de abertura: 0% = arregalado, 100% = quase fechado.
  openTarget = 1.0f - 0.72f * (VAL_OLHOS / 100.0f);
  if (blinking) openTarget = 0.0f;

  // Suavizacao exponencial para a animacao nao ficar dura.
  openNow += (openTarget - openNow) * 0.28f;

  // Olho de tonto: a metrica dos olhos estourando, ou uma compactacao em curso.
  const bool     crossed = (VAL_OLHOS >= 95) || (strcmp(st.mode, "compact") == 0);
  const int16_t  eyeH    = (int16_t)(EYE_RY * openNow);
  const uint16_t iris    = levelColor(VAL_OLHOS);

  if (eyeH != lastEyeH || crossed != lastCrossed ||
      VAL_OLHOS != lastDrawnOlhos || asleep != lastAsleep) {
    drawEye(EYE_CX_L, EYE_CY, eyeH, iris, crossed, asleep);
    drawEye(EYE_CX_R, EYE_CY, eyeH, iris, crossed, asleep);
    lastEyeH       = eyeH;
    lastCrossed    = crossed;
    lastDrawnOlhos = VAL_OLHOS;
    lastAsleep     = asleep;
  }

  if (VAL_BARRA != lastDrawnBarra) {
    drawBar(VAL_BARRA);
    lastDrawnBarra = VAL_BARRA;
  }

  delay(16);  // ~60 fps
}

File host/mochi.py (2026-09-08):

#!/usr/bin/env python3
"""claude-mochi — lado do PC, em um arquivo so.

Substitui o trio statusline-mochi.sh + mochi-mode.sh + mochi-serial.py por um
unico programa Python. Motivo: no Windows nao existe `jq` nem `bash` por
padrao, e a status line do Claude Code e executada pelo Git Bash (quando
instalado) ou pelo PowerShell. Um script bash que depende de `jq` simplesmente
nao roda la.

Os .sh continuam no repositorio para quem ja os tem funcionando no Linux/macOS.
No Windows — e com o Claude Desktop — use este arquivo.

Subcomandos:

    mochi.py install        instala em ~/.claude e configura settings.json
    mochi.py statusline     status line do Claude Code (le JSON no stdin)
    mochi.py mode busy      publica o modo (chamado pelos hooks)
    mochi.py bridge         ponte serial em primeiro plano (com log)
    mochi.py start|stop     ponte serial em segundo plano
    mochi.py doctor         diagnostico: portas, ponte, firmware
    mochi.py ports          lista as portas e a nota de cada uma
    mochi.py send "..."     manda uma linha crua para o mochi (teste)
    mochi.py uninstall      remove o que o install colocou

Arquitetura (a mesma de antes, e pelos mesmos motivos):

  A status line NUNCA abre a porta serial. Abrir a porta mexe em DTR/RTS e
  REINICIA o ESP8266 — isso aconteceria a cada mensagem do Claude. Quem segura
  a porta aberta e a ponte, um processo so, que fica rodando. A status line
  apenas escreve arquivos de estado (escrita atomica) e sai na hora.

  A ponte reenvia o estado a cada --interval segundos mesmo sem mudanca, entao
  se o ESP reiniciar ele se recupera sozinho em poucos segundos.

Requer pyserial apenas para a ponte:  pip install pyserial
A status line e os hooks funcionam sem ele (so escrevem arquivos).
"""

from __future__ import annotations

import argparse
import json
import os
import pathlib
import subprocess
import sys
import time

IS_WINDOWS = os.name == "nt"
HOME_CLAUDE = pathlib.Path(os.path.expanduser("~")) / ".claude"

STATE_FILE = pathlib.Path(os.environ.get("MOCHI_STATE_FILE", HOME_CLAUDE / "mochi-state"))
MODE_FILE = pathlib.Path(os.environ.get("MOCHI_MODE_FILE", HOME_CLAUDE / "mochi-mode"))
PORT_CACHE = HOME_CLAUDE / "mochi-port"          # ultima porta que funcionou
BEAT_FILE = HOME_CLAUDE / "mochi-bridge.beat"    # ponte viva? (pid + mtime)
LOG_FILE = HOME_CLAUDE / "mochi-bridge.log"

BAUD = 115200

# Se o batimento da ponte estiver mais velho que isto, consideramos que ela
# morreu e subimos outra. Bem maior que o intervalo de batimento (2 s) para
# aguentar a maquina engasgar por um instante sem duplicar processo.
BEAT_STALE_S = 20.0


# ============================================================ portas seriais ==

# VID:PID dos conversores USB-serial usados nas placas ESP8266/ESP32 comuns.
KNOWN_ADAPTERS = {
    (0x1A86, 0x7523): "CH340",
    (0x1A86, 0x7522): "CH340",
    (0x1A86, 0x55D4): "CH9102",
    (0x10C4, 0xEA60): "CP2102",
    (0x10C4, 0xEA70): "CP2105",
    (0x0403, 0x6001): "FT232",
    (0x0403, 0x6015): "FT231X",
    (0x303A, 0x1001): "ESP32-S2/S3 USB nativo",
    (0x2341, 0x0043): "Arduino Uno",
    (0x2A03, 0x0043): "Arduino Uno (clone)",
}

# Pedacos de descricao que denunciam uma porta que NAO e o mochi. Este PC de
# teste tem oito COM de Bluetooth; sem esta lista o autodetect vira loteria.
BLACKLIST_HINTS = ("bluetooth", "bthenum", "virtual", "com0com", "vspd")


def _import_serial():
    """Importa o pyserial com uma mensagem util se ele faltar."""
    try:
        import serial                        # noqa: F401
        from serial.tools import list_ports  # noqa: F401
        return serial, list_ports
    except ImportError:
        sys.exit(
            "faltou o pyserial. instale com:\n"
            f"    {sys.executable} -m pip install pyserial"
        )


def score_port(p) -> tuple[int, str]:
    """Da uma nota para a porta. Maior = mais provavel de ser o mochi.

    Nao basta 'e uma porta COM': num Windows tipico a maioria das COM sao
    Bluetooth. A nota combina VID:PID conhecido, descricao e tipo de barramento.
    """
    desc = f"{p.description} {p.hwid} {getattr(p, 'manufacturer', '') or ''}".lower()

    for hint in BLACKLIST_HINTS:
        if hint in desc:
            return -100, f"ignorada ({hint})"

    if p.vid is not None and (p.vid, p.pid) in KNOWN_ADAPTERS:
        return 100, f"adaptador conhecido: {KNOWN_ADAPTERS[(p.vid, p.pid)]}"

    for nome in ("ch340", "ch910", "cp210", "ftdi", "ft232",
                 "silicon labs", "esp32", "usb-serial", "usb serial"):
        if nome in desc:
            return 60, f"descricao parece USB-serial ({nome})"

    if p.vid is not None:
        return 30, "dispositivo USB generico"

    return 0, "porta sem VID (provavelmente nao e USB)"


def list_candidates():
    """Portas ordenadas da mais provavel para a menos."""
    _, list_ports = _import_serial()
    linhas = []
    for p in list_ports.comports():
        nota, motivo = score_port(p)
        linhas.append((nota, p.device, p.description, motivo))
    linhas.sort(key=lambda r: (-r[0], r[1]))
    return linhas


def probe_port(port: str, timeout: float = 2.5) -> bool:
    """Abre a porta e pergunta se tem um mochi do outro lado.

    O firmware responde 'ok' para cada linha recebida. Se responder, e ele.
    Isso resolve o caso de duas placas ligadas ao mesmo tempo: em vez de
    desistir com 'achei mais de uma placa', perguntamos para cada uma.
    """
    try:
        ser = open_serial(port, BAUD, settle=1.6)
    except Exception:
        return False
    try:
        ser.reset_input_buffer()
        ser.write(b"ctx=0 win=0 state=idle\n")
        ser.flush()
        fim = time.monotonic() + timeout
        buf = b""
        while time.monotonic() < fim:
            buf += ser.read(64)
            if b"ok" in buf or b"mochi" in buf:
                return True
            time.sleep(0.05)
        return False
    finally:
        try:
            ser.close()
        except Exception:
            pass
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

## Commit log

2026-08-16 Adiciona firmware, status line e case do claude-mochi
    Mochi de mesa cujos olhos indicam o consumo de tokens do Claude Code.
    - firmware/: sketch ESP8266 + ST7789 240x240. Wi-Fi em modo station com
    mDNS (mochi.local) em vez do hotspot do projeto de referencia, e um
    endpoint /tokens que recebe as porcentagens de contexto e limite de 5h.
    A abertura da palpebra e a cor da iris derivam do contexto usado; a
    barra inferior mostra o limite de 5h.
    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
    [mochi.scad]
2026-08-16 Adiciona ligacao por serial USB, para PC e mochi em redes diferentes
    O modo Wi-Fi so funciona se PC e mochi estiverem na mesma rede sem
    isolamento de cliente. Em rede corporativa isso quase nunca vale: o
    ESP8266 nao entra em WPA2-Enterprise, e mesmo na mesma SSID o AP
    isolation bloqueia trafego entre dispositivos. Como o mochi ja fica no
    USB para ter energia, serial e o caminho natural.
    - firmware: modos selecionaveis LINK_SERIAL / LINK_WIFI. No modo serial
    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
2026-08-16 Remove __pycache__ commitado por engano
    Gerado pelo py_compile durante o teste de sintaxe. Adiciona ao gitignore.
    Claude-Session: https://claude.ai/code/session_01WEUs4Ju4uHE3d2DeXM3vQA
2026-08-16 Corrige guia de compra do display e suporta modulos sem pino CS
    O README dizia "modulo de 7 pinos (com CS)", o que esta errado e levaria
    a comprar o item confuso: os modulos ST7789 240x240 de 7 pinos NAO tem
    CS (fica em GND internamente); quem tem CS sao os de 8 pinos.
    As duas variantes servem aqui, porque o display e o unico dispositivo no
    barramento SPI - a unica desvantagem do sem-CS e nao poder dividir o SPI
    com outro periferico. TFT_CS agora aceita -1 para esses modulos.
    Acrescenta ao README qual tamanho comprar (1.54" pela area ativa maior,
    1.3" como alternativa de firmware identico), o que evitar, e duas
    armadilhas que nao aparecem na lista de pecas: a barra de pinos costuma
    vir sem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
    [claude_mochi.ino]
2026-08-16 Simplifica o caminho de protoboard: menos fios e teste sem PC
    O objetivo aqui e validar o hardware antes de tocar em qualquer
    configuracao do PC, porque cada peca que entra junto vira uma variavel a
    mais quando algo nao funciona.
    - USE_BLK_PIN, com padrao 0: BLK vai direto no 3V3. Perde o controle de
    brilho, que nao serve para nada nesta fase, e tira um fio.
    - BOOT_DEMO: ao ligar, os olhos varrem 0 -> 100 -> 0% de contexto. Se a
    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
2026-08-16 Transforma o guia de compra do display em checklist aprova/rejeita
    Facilita comparar anuncios um a um. Acrescenta o GC9A01 a lista de
    rejeitados com o motivo (funciona, mas e redondo - pertence a variante
    de dois olhos separados, nao a esta) e os modelos de resolucao proxima
    que quebrariam o layout.
    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
2026-08-16 Adiciona modelo 3D imprimível da carcaça do mochi
    Carcaça paramétrica em OpenSCAD, em duas peças que imprimem sem suporte:
    casca (corpo oco, rosto gravado, grelha e aberturas das portas) e base
    (espaçadores da PCB, ventilação, escareados e rebaixo dos pés).
    - boards.scad descreve cada placa (tamanho, furos, portas); vêm prontos
    Raspberry Pi Zero/Zero 2 W e Pi Pico
    - aberturas de parede com teto em 45 graus, autoportantes
    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
    [boards.scad, mochi.scad, pi_zero-base.stl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]
2026-08-16 Adiciona mapa visual do que a tela desenha
    SVG com as telas em escala 1:1, geradas a partir das mesmas constantes e da
    mesma matemática inteira do firmware (rampa de contexto, piscar, dormir,
    X_X de compactação) mais uma proposta de expressões vindas dos hooks.
    O gerador em Python fica junto para o desenho continuar batendo com o
    firmware quando as constantes mudarem.
    Claude-Session: https://claude.ai/code/session_01NNKoZx2hi8NDCEkgjpk1bC
2026-08-17 Adiciona mapa visual do que a tela desenha
    mesma matemática inteira do firmware: rampa de contexto (olho de 34 px a
    9 px, íris verde -> âmbar -> vermelho), piscar, cochilar e o X_X de
    compactação. Traz também uma proposta de expressões vindas dos hooks
    (perguntando, trabalhando, procurando, erro, resolveu, falando), com o
    vocabulário de state correspondente.
    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
    [gera_svg.py]
2026-08-17 Conserta as duas peças soltas na metade frontal do case
    O STL da frente saía com três sólidos desconexos em vez de um. O fatiador
    imprimiria dois deles como peças avulsas boiando dentro da caixa.
    Lábio de encaixe: ficava na faixa y >= split_y e rebaixado lip_fit em
    relação à parede, então não encostava na casca nem em y nem em raio.
    Agora tem um trecho de solda que invade a metade frontal por lip_weld nos
    dois sentidos; a faixa que entra na tampa continua com a folga de antes.
    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
    [mochi.scad]
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2026-08-26 Adiciona o modo so_display ao case parametrico
    So o display vai dentro do mochi: o ESP8266 fica de fora, ligado por jumpers,
    como em docs/PROTOBOARD.md. Com so_display a prateleira da placa e o recorte
    do USB nao sao gerados, e entra no lugar uma saida de 12 x 5 mm para o chicote.
    A metade "back" fecha como solido unico. A "front" nao foi verificada: o casco
    de 12 esferas com $fn=64 passa de 40 min no CGAL nesta maquina.
    [mochi.scad]
2026-08-26 Abre a janela do display na carcaca do Clawd
    Trabalha em cima das malhas do clawd_mochi.3mf: chapa frontal de 2 mm e corpo
    com cavidade passante, achatado em Z de 38 para 28 mm pela matriz do objeto
    (m22 = 0,7368). O modelo original tem a cara vazada, nao uma tela.
    Acrescenta a janela da area ativa com chanfro de 45 graus, tapa a boca (a borda
    da janela caia no meio dela) e poe uma moldura interna que segura a PCB contra
    a chapa, com saia a 45 graus para nao precisar de suporte ali dentro. Sem
    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
    [clawd_tela.scad]
2026-09-01 Conserta a compilacao do modo serial
    O include de ESP8266WiFi.h estava dentro de #if LINK_WIFI, mas o setup()
    chama WiFi.mode(WIFI_OFF) e forceSleepBegin() no bloco oposto, o de
    LINK_SERIAL && !LINK_WIFI. No modo padrao — que e o recomendado no README —
    o header nunca era incluido e o sketch nao compilava:
    claude_mochi.ino:363:3: error: 'WiFi' was not declared in this scope
    Move o include para fora do #if. O modo Wi-Fi segue igual.
    [claude_mochi.ino]
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
